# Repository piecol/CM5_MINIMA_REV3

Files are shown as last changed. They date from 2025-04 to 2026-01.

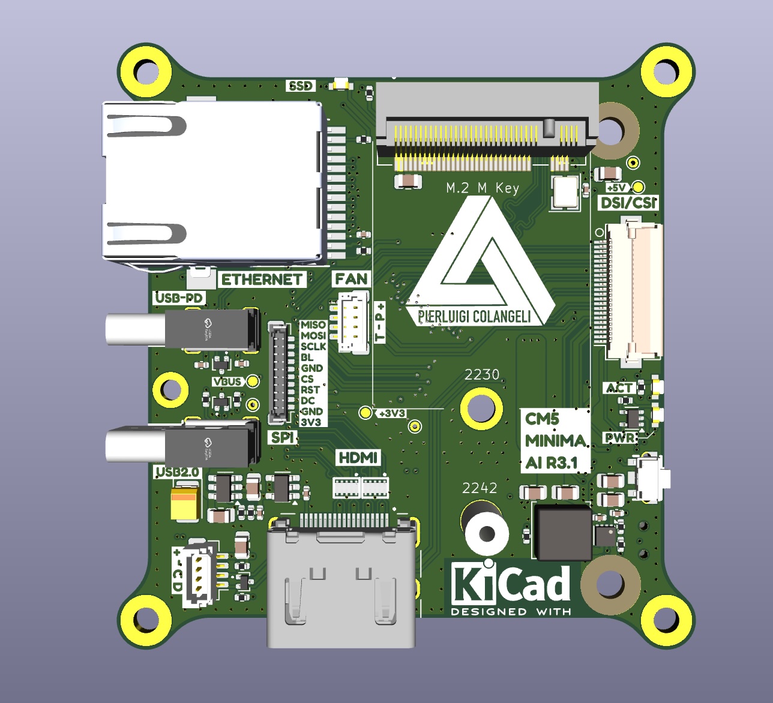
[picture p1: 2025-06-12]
jlcpcb/production_files/front.jpg

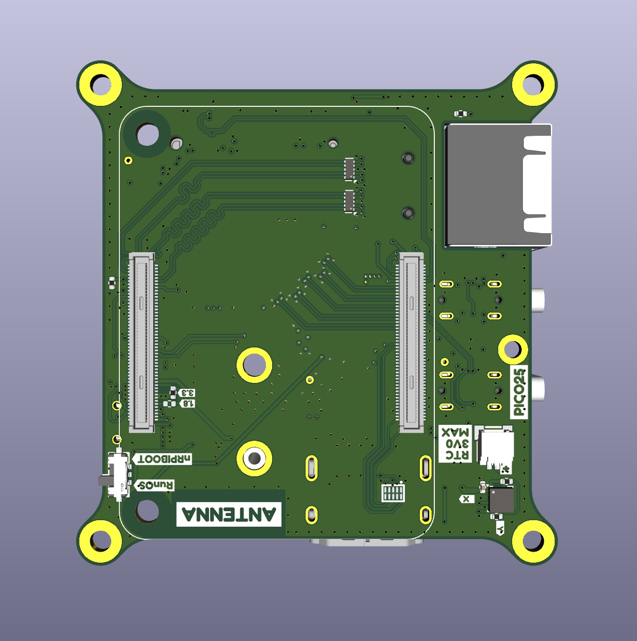
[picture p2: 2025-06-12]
jlcpcb/production_files/back.jpg

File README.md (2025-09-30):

# CM5 MINIMA REV3

## Introduction

The **CM5 MINIMA REV3** is a compact carrier board for the latest Raspberry Pi computing module 5.
It is designed for embedded applications, DIY electronics, and low-power computing projects. Unlike traditional desktop computers, the CM5 is a small, efficient system that integrates essential computing hardware onto a single board. Whether you're a hobbyist, developer, or engineer, this module provides a versatile platform for various applications, including IoT, automation, and custom hardware development.

If you're not familiar with Raspberry Pi or single-board computers (SBCs), think of the CM5 as a miniaturized computer that can handle tasks like data processing, networking, and hardware control, all while fitting in the palm of your hand. 
https://www.raspberrypi.com/products/compute-module-5/?variant=cm5-104032



Get to know the story behind the MINIMA on Hackster.io:

https://www.hackster.io/piecol/tiny-open-source-media-streamer-with-lorawan-what-a98a93

3d

## Designed with KiCad

MINIMA was developed using KiCad, a powerful open-source Electronic Design Automation (EDA) tool. KiCad enables designers to create high-quality PCB layouts and schematics while maintaining full control over their hardware designs. By leveraging open-source tools like KiCad, the CM5 MINIMA REV3 embraces accessibility, collaboration, and innovation in hardware development.

## NextPCB production ready

This project is kindly supported by [NextPCB](https://www.nextpcb.com/), an excellent KiCAD-friendly PCB manufacturer.
Under "nextpcb/production_files" you can find production files to directly place your order.
Explore thier blog https://www.nextpcb.com/blog/exploring-the-cm5-minima-rev3

## Key Features

- **USB-C Power Delivery (PD):** Supports power negotiation for efficient energy use.
- **USB 2.0 Ports:** Connect peripherals such as keyboards, mice, and external storage.
- **Gigabit Ethernet:** High-speed wired networking with a low-profile cutout magjack.
- **HDMI Port:** Output video to external displays for media playback or interface applications.
- **M.2 M Key Slot:** Supports 2230/2242 SSDs for fast storage expansion.
- **CSI/DSI Connector:** Attach camera modules or displays for vision-based applications.
- **LIS3DH STM32 Sensor:** Built-in accelerometer.
- **I2C Connector (3.3V only):** Connect low-power sensors and communication modules.
- **SPI Connector:** Supports high-speed communication with other devices.
- **Fan Connector:** Optional cooling support for high-performance applications.
- **Status LEDs:** Visual indicators for power and system activity.
- **Compact Size:** Measuring only **5.4 × 5.7 cm**, ideal for space-constrained projects.

pcb

## Schematics

[PDF SCHEMATICS](https://github.com/piecol/CM5_MINIMA_REV3/blob/main/CM5_MINIMA_3.pdf)

## Getting Started

To use the **CM5 MINIMA REV3**, you'll need:

- A **USB-C power adapter** that supports Power Delivery (PD).
- A **display (HDMI)** and **input devices (USB keyboard/mouse)** for setup.
- A **network connection** (Ethernet or Wi-Fi via an external adapter if needed).

## Flashing OS

To flash an operating system (OS) to the CM5, use the switch located on the bottom of the board to enable flashing mode. It is equivalent to the "Fit nRPI_BOOT to J2 (disable eMMC Boot) on the IO board jumper." on the CM5 IO board.
Please refere to the official guidelines for further instructions:
https://www.raspberrypi.com/documentation/computers/compute-module.html#set-up-the-io-board

aseembly

## Applications

- **IoT & Smart Devices:** Use sensors and network capabilities to create connected applications.
- **Home Automation:** Control and monitor home devices with minimal power consumption.
- **Embedded Systems:** Develop custom hardware solutions for industrial and consumer electronics.
- **Media Centers:** Play videos and manage digital content on an external display.
- **DIY Projects:** Ideal for makers and educators learning about electronics and programming.

## CNC casing

Custom casing with passive heat-sink was supported by PCBway, grab the .STEP file in the CNC_enclosure folder and order yours.



## Conclusion

The **CM5 MINIMA REV3** is a powerful and flexible computing module that opens up endless possibilities for embedded computing and automation. Whether you're building a smart device, experimenting with sensors, or designing a networked system, this board provides the essential features you need in a compact, energy-efficient form factor.

## **Stackup**:
6L (SIG:PWR | GND | SIG-PWR | PWR | GND | SIG:PWR) 

### If you would like to support me:

"Buy Me A Coffee" (https://www.buymeacoffee.com/pierluigicj)

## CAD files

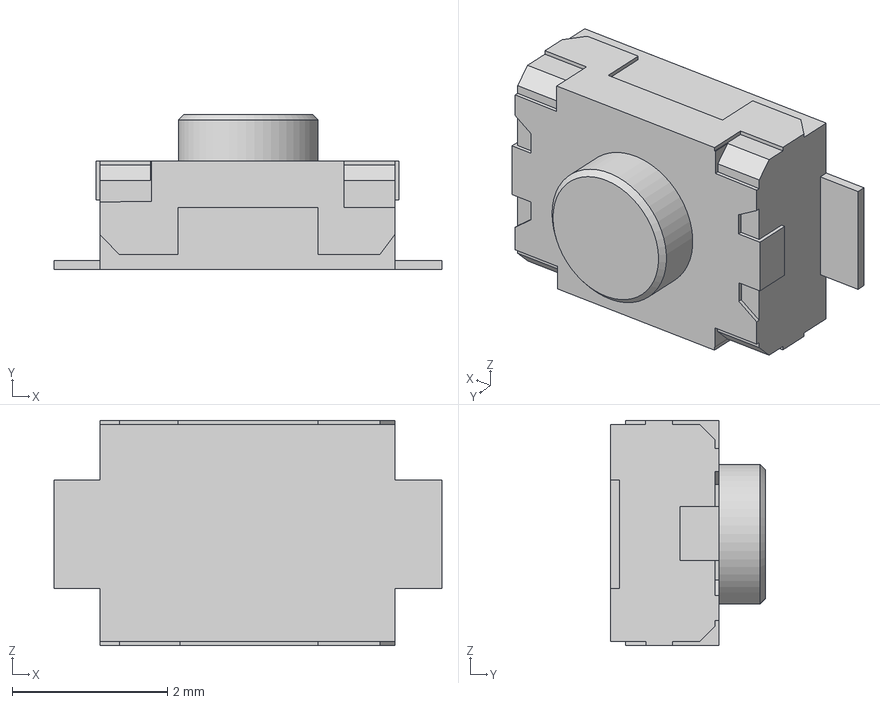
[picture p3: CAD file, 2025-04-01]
3d_lib/3x4x2 tact button.step
5.00 x 2.00 x 2.90 mm

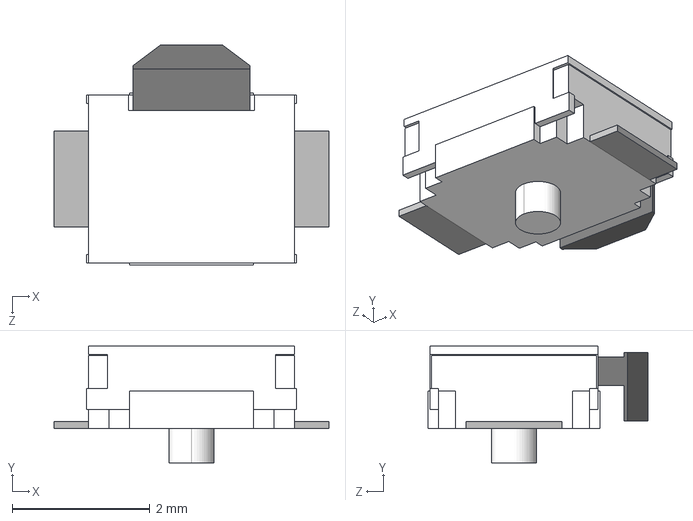
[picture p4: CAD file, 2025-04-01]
3d_lib/LIB_B3U-3000PM-B/B3U-3000PM-B/3D/B3U-3000PM-B.stp
4.00 x 1.70 x 3.20 mm

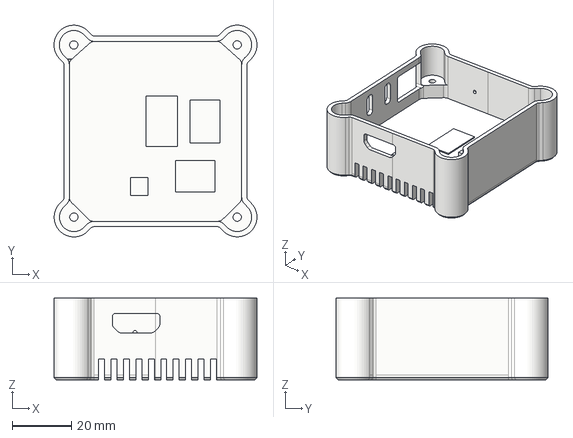
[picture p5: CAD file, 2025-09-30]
CNC_enclosure/MINIMA CASE 3_BOX v1.step
68.3 x 71.3 x 27.4 mm

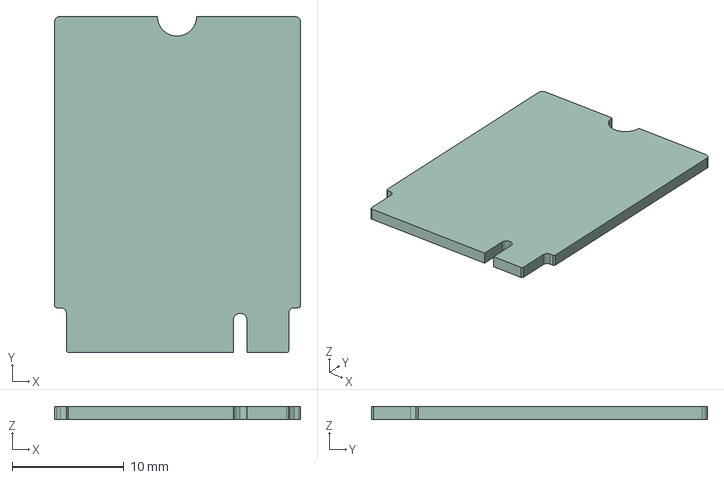
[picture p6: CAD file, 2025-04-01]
3d_lib/M.2-B.step
22.0 x 30.1 x 1.20 mm

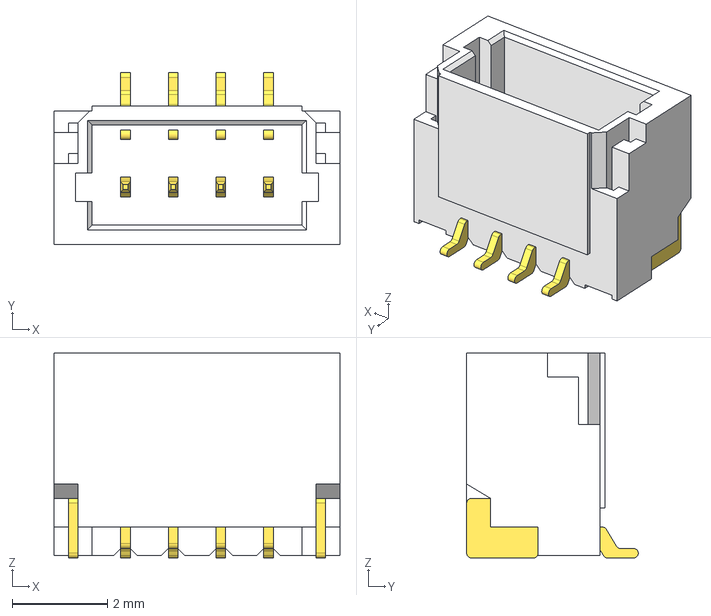
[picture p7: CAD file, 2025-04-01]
3d_lib/BM4B-SRSS-TB.step
6.00 x 3.60 x 4.30 mm

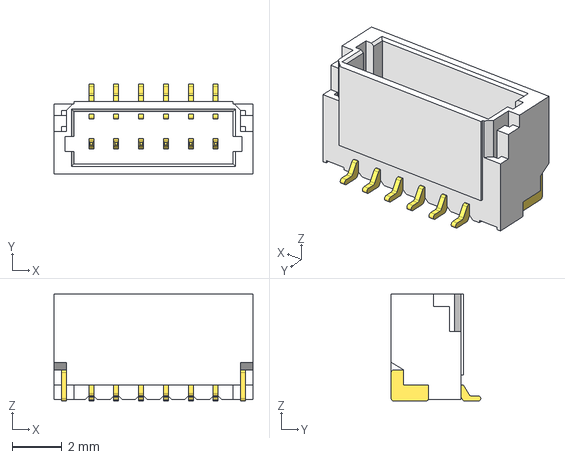
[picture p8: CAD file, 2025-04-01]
3d_lib/BM6B-SRSS-TB.step
8.00 x 3.60 x 4.30 mm

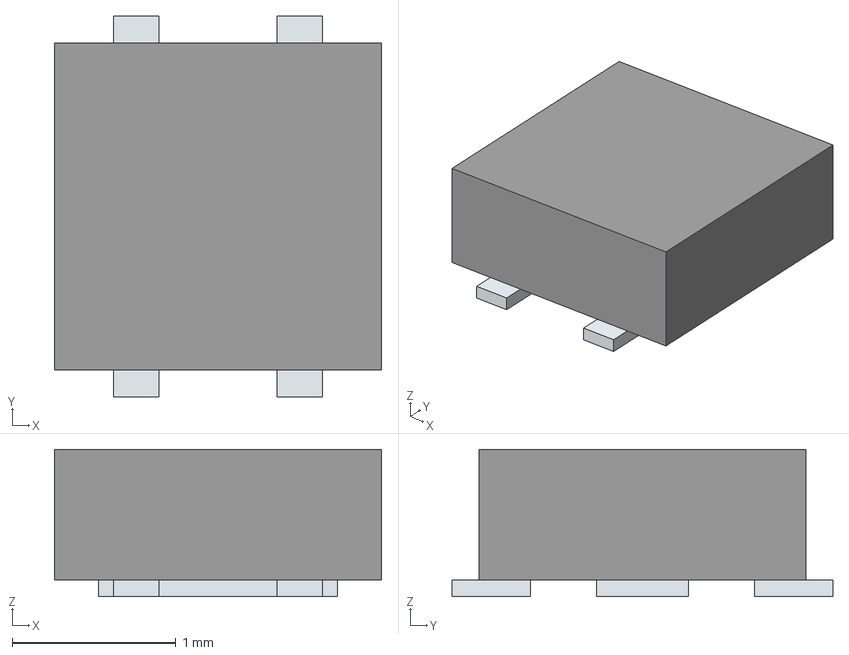
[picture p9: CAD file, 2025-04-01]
3d_lib/SHTC3-TR-10KS.stp
2.00 x 2.33 x 0.9 mm
Pins

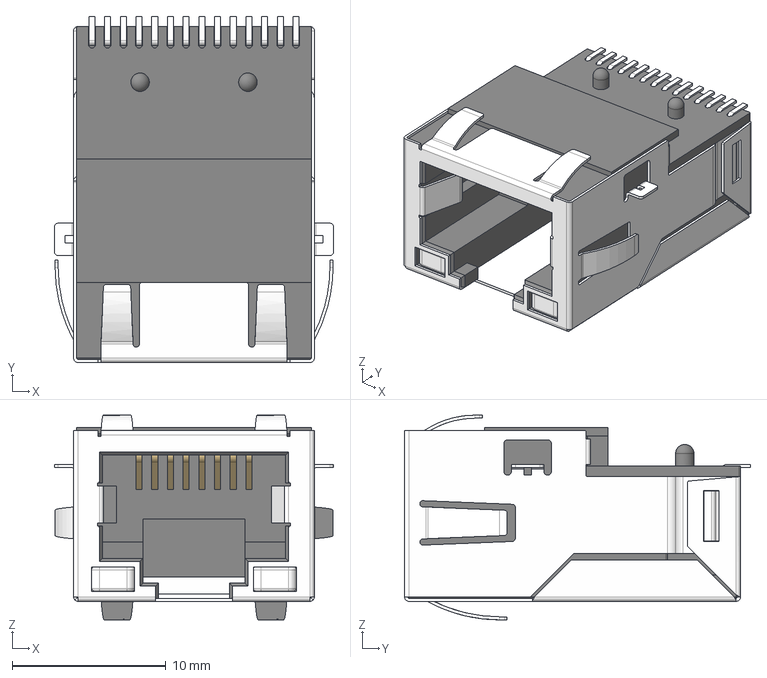
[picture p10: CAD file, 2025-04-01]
3d_lib/WE-RJ45LAN-7498111120AR (rev1).stp
18.1 x 22.5 x 13.3 mm
Shielding
Insulator x 3

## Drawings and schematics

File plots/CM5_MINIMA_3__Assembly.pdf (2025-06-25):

# kibuzzard-67CC6BD3

# kibuzzard-6772DA33

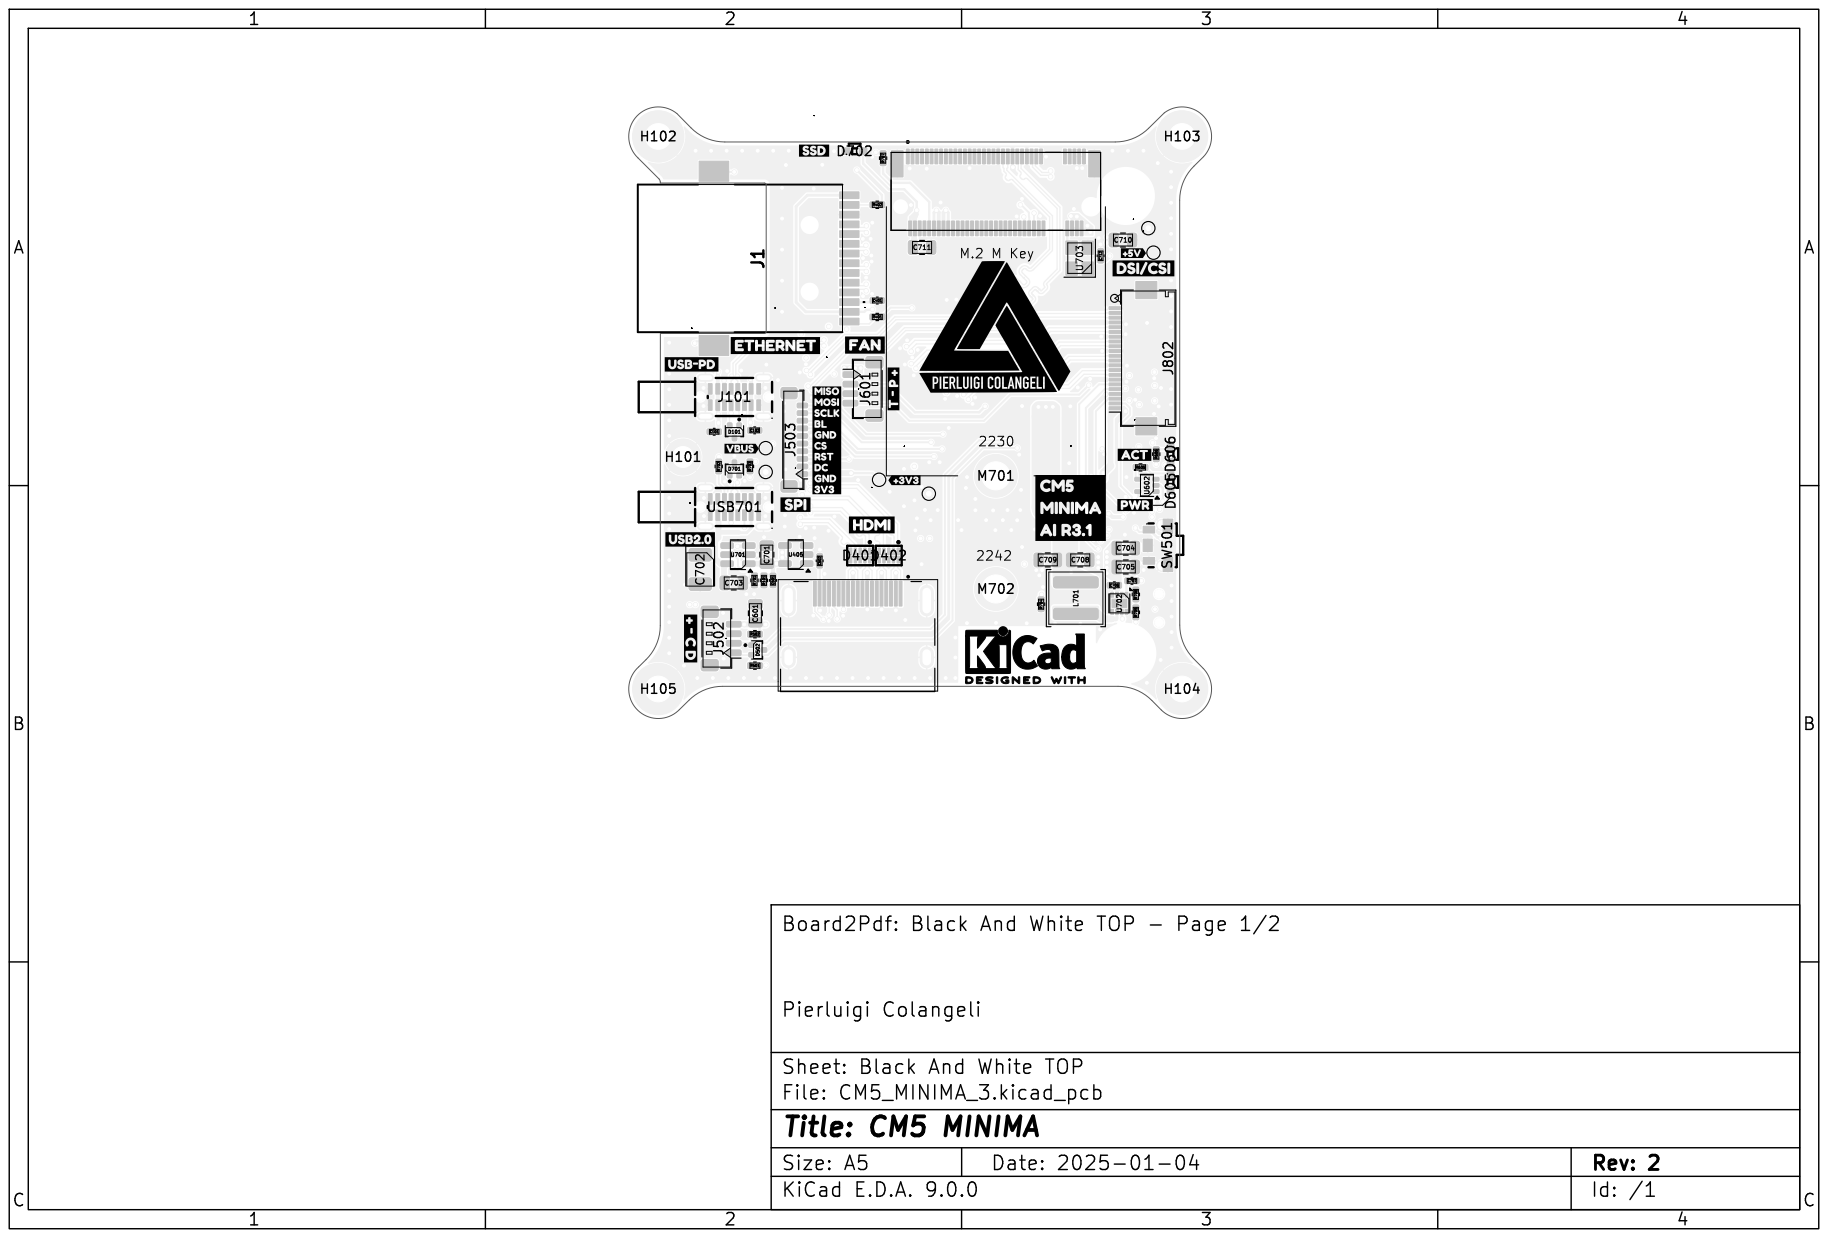
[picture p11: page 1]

File: CM5_MINIMA_3.kicad_pcb Sheet: Black And White TOP
Id: /1 Title: CM5 MINIMA

kibuzzard-67EBF0A0 1 | 2 | 3 | 4

A

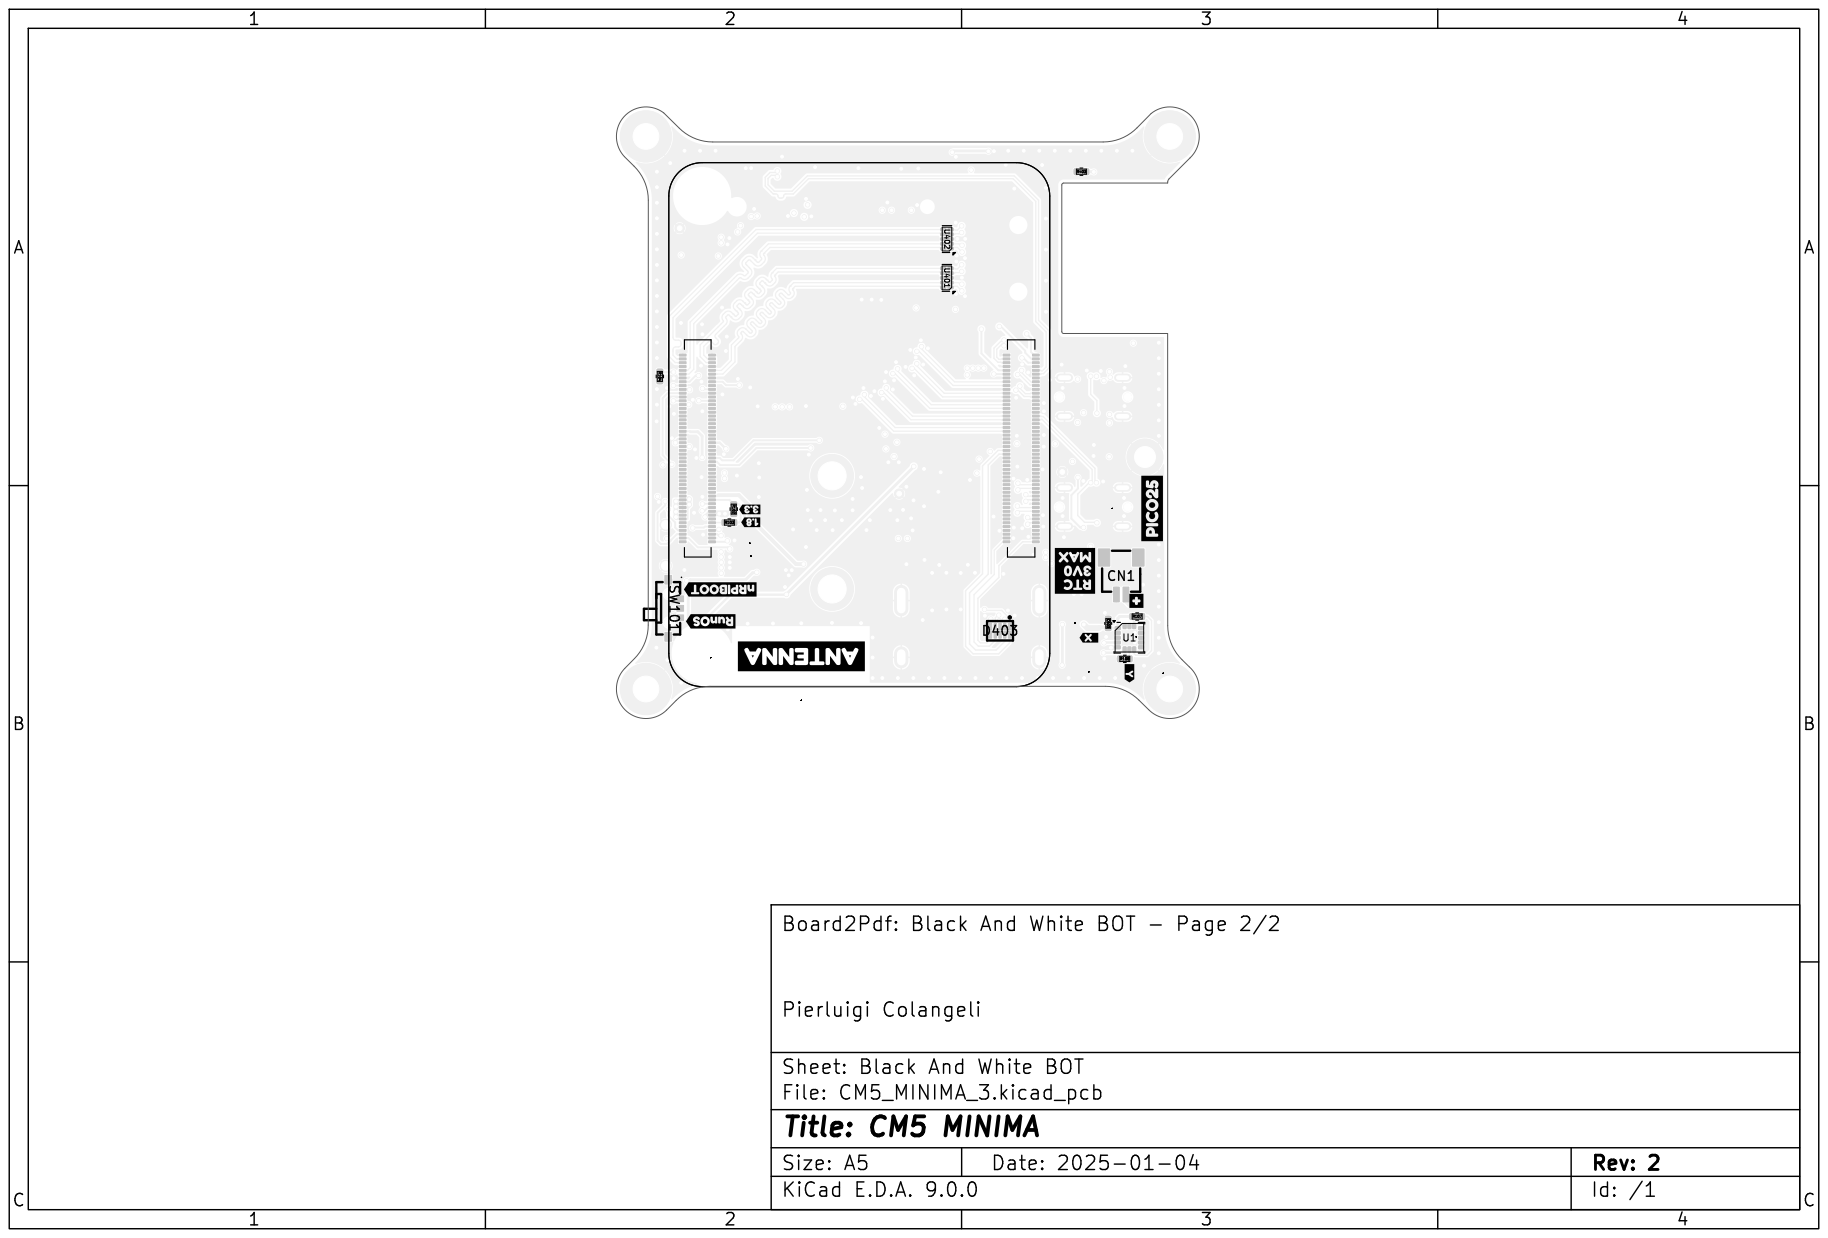
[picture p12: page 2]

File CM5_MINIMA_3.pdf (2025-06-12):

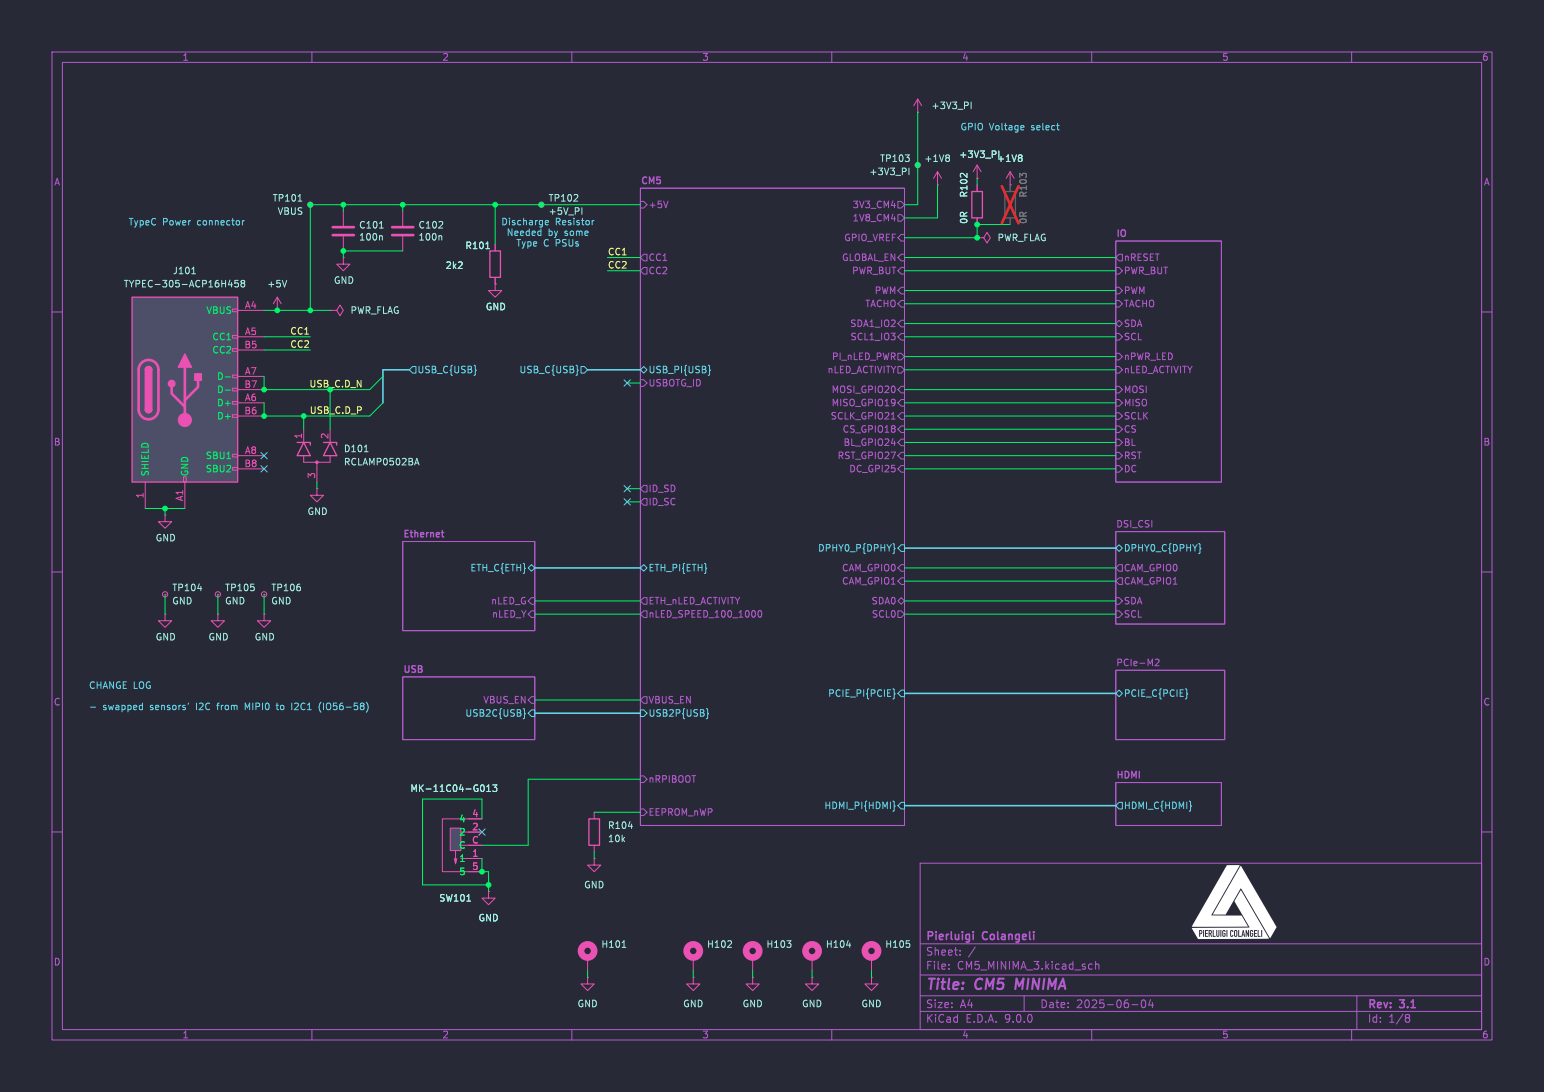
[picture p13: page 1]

HDMI_C{HDMI} HDMI SCL SDA DPHY0_C{DPHY} CAM_GPIO0 CAM_GPIO1 DSI_CSI nRESET SDA
SCL PWR_BUT PWM
TACHO MOSI MISO

File: CM5_MINIMA_3.kicad_sch Sheet: / Pierluigi Colangeli VBUS_EN

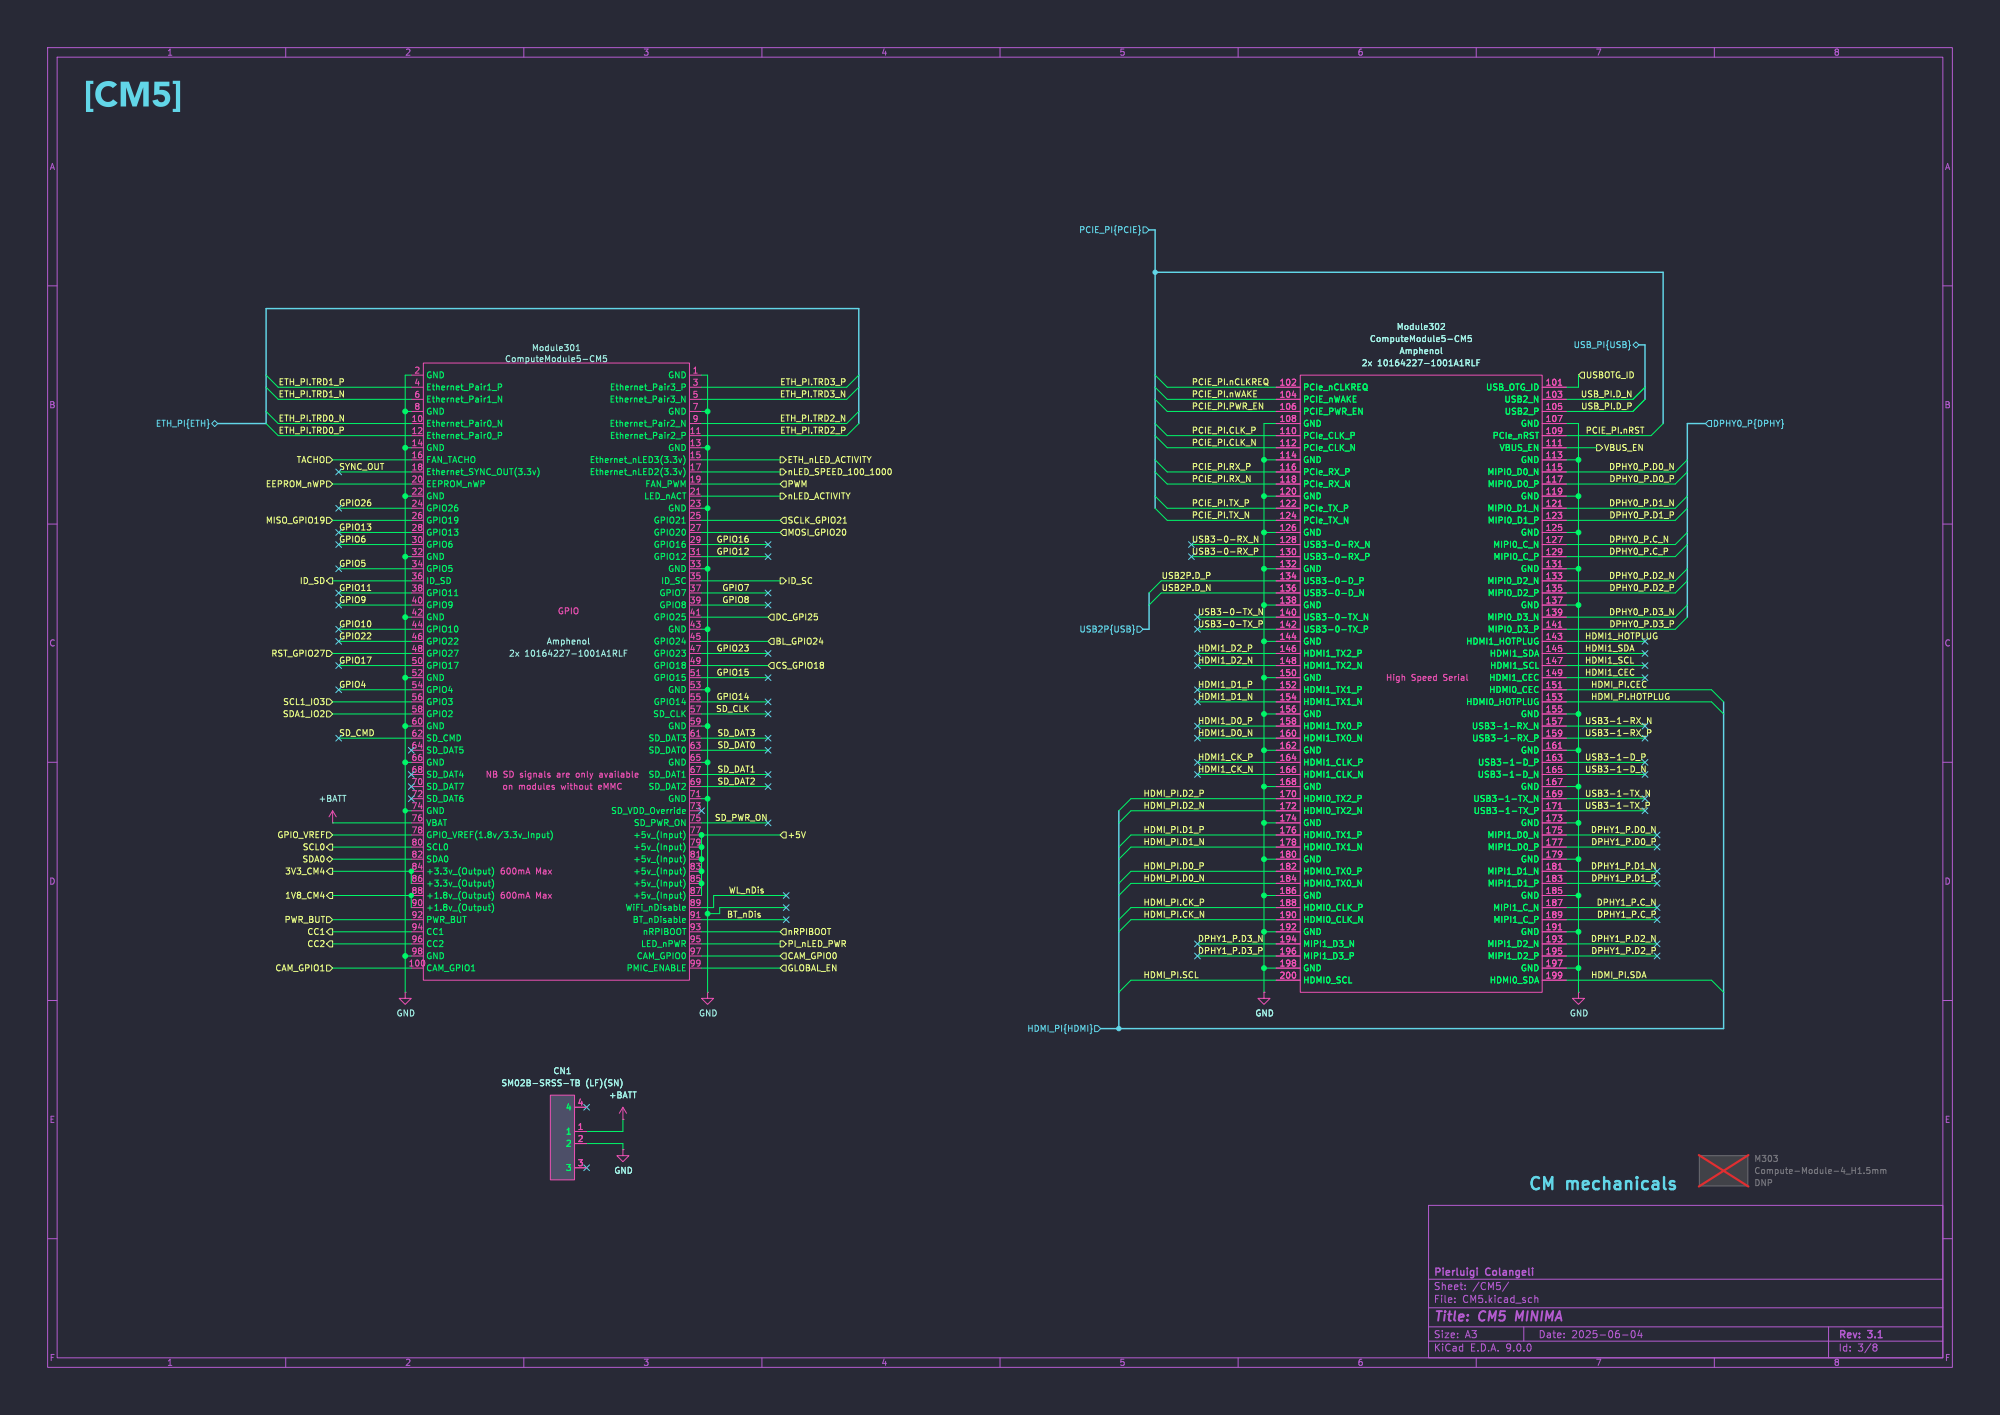
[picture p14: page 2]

USB_PI{USB} MISO_GPIO19 RST_GPIO27
ID_SD 36 GPIO11 38 GPIO9 40 GND 42 GPIO10 44 GPIO22 46 GPIO27 48 GPIO17 50 GND 52 GPIO4 54 GPIO3 56 GPIO2 58 GND 60 SD_CMD 62 SD_DAT5 64 GND 66 SD_DAT4 68 SD_DAT7 70 SD_DAT6 72 GND 74 VBAT 76 GPIO_VREF(1.8v/3.3v_Input) 78 SCL0 80 SDA0 82 +3.3v_(Output) 84 +3.3v_(Output) 86 +1.8v_(Output) 88 +1.8v_(Output) 90 PWR_BUT 92 CC1 94 CC2 96 GND 98 CAM_GPIO1 100

GND 2 Ethernet_Pair1_P 4 Ethernet_Pair1_N 6 GND 8 Ethernet_Pair0_N 10 Ethernet_Pair0_P 12 GND 14 FAN_TACHO 16 Ethernet_SYNC_OUT(3.3v) 18 EEPROM_nWP 20 GND 22 GPIO26 24 GPIO19 26 GPIO13 28 GPIO6 30 GND 32 GPIO5 34

on modules without eMMC GPIO

600mA Max 600mA Max NB SD signals are only available

File: CM5.kicad_sch Sheet: /CM5/ Pierluigi Colangeli GND

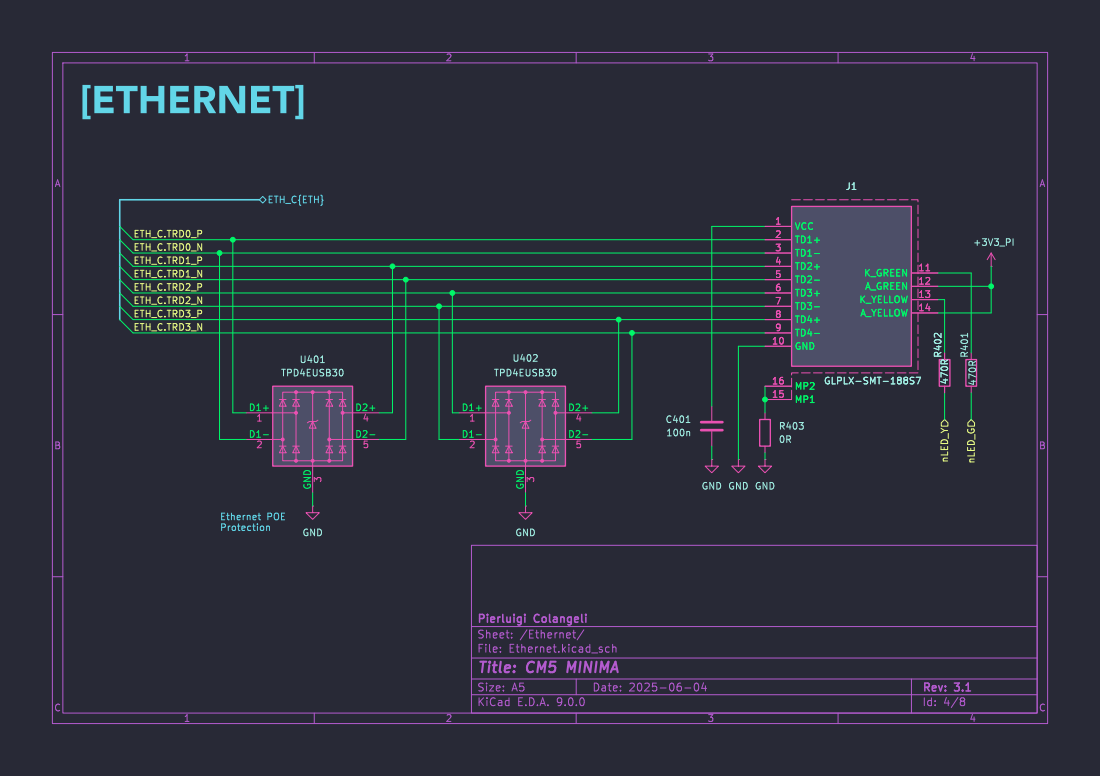
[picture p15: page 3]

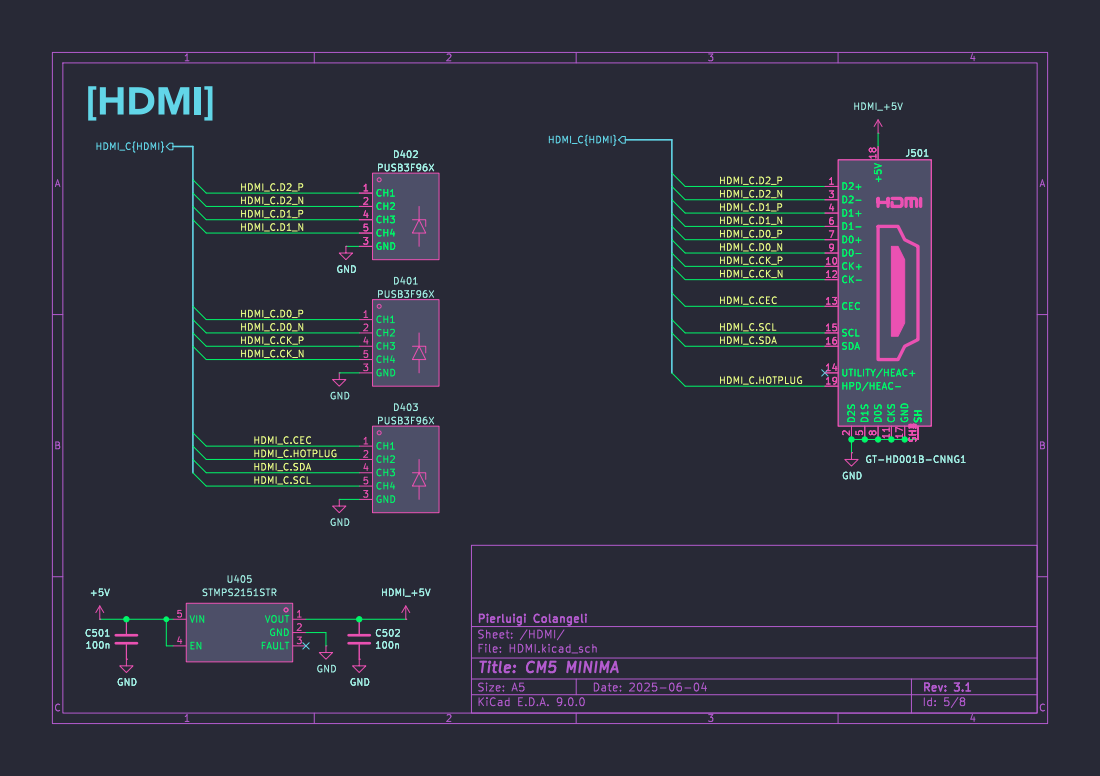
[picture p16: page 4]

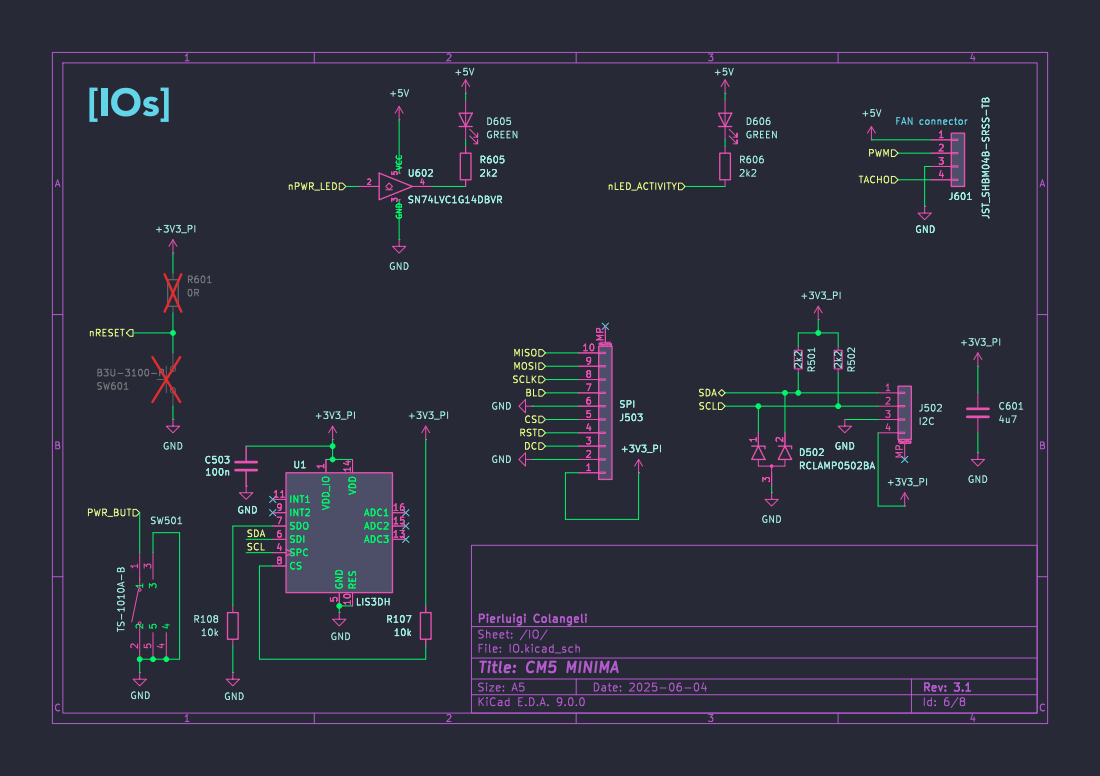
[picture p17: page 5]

nLED_ACTIVITY RST DC MOSI MISO

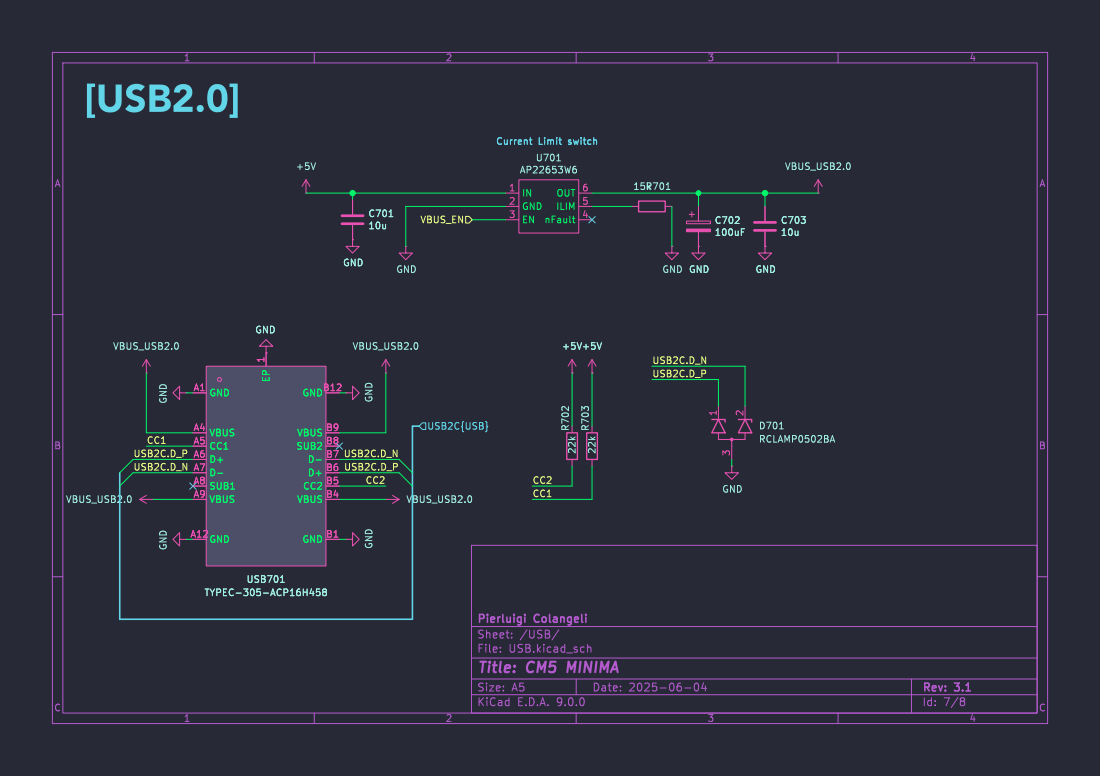
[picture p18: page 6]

1 GNDB12 VBUS B9 SUB2 B8 D- B7 D+ B6 CC2 B5 VBUS B4 GND B1 USB701 TYPEC-305-ACP16H458 GND GND GND GND

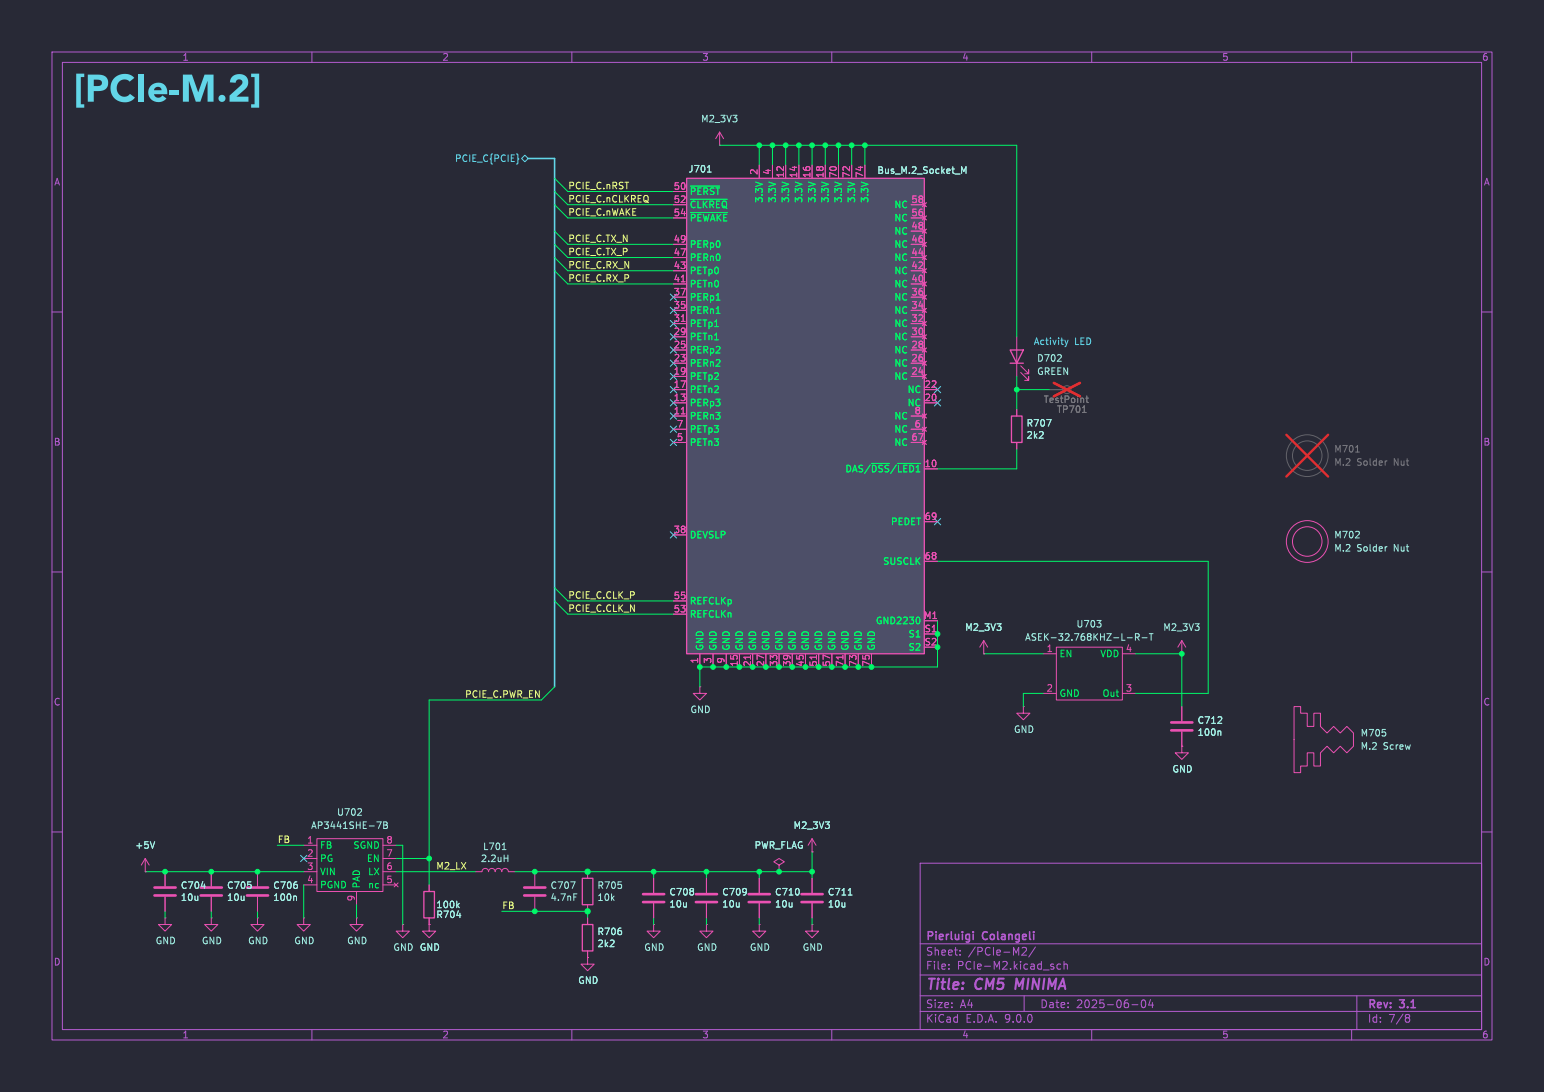
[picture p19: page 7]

4 GND 33 3.3V 12 GND 39 3.3V 14 GND 45 3.3V 16 GND 51 3.3V 18 GND 57 3.3V 70 GND 71 3.3V 72 GND 73 3.3V 74 GND 75 NC 58 NC 56 NC 48 NC 46 NC 44 NC 42 NC 40 NC 36 NC 34 NC 32 NC 30 NC 28 NC 26 NC 24 NC 8 NC 6 NC 67 NC 22 NC 20 DAS/~{DSS}/~{LED1} 10 PEDET 69 SUSCLK 68 GND2230 M1 S1 S1 S2 S2 C705

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

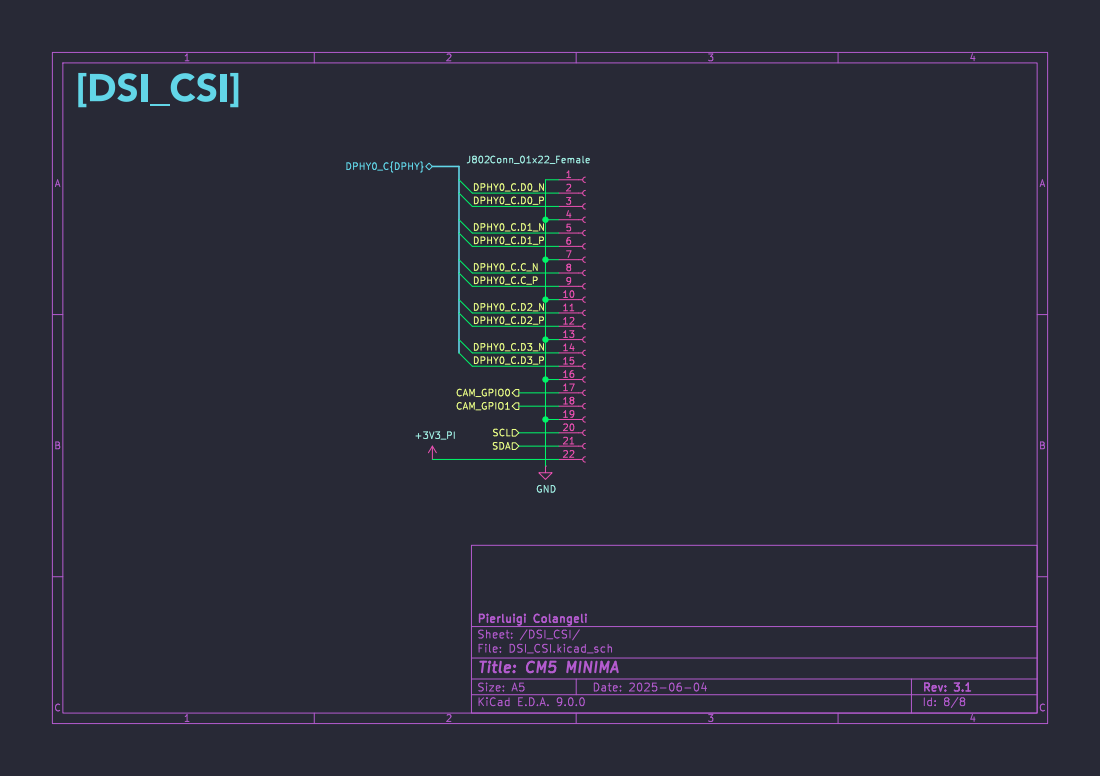
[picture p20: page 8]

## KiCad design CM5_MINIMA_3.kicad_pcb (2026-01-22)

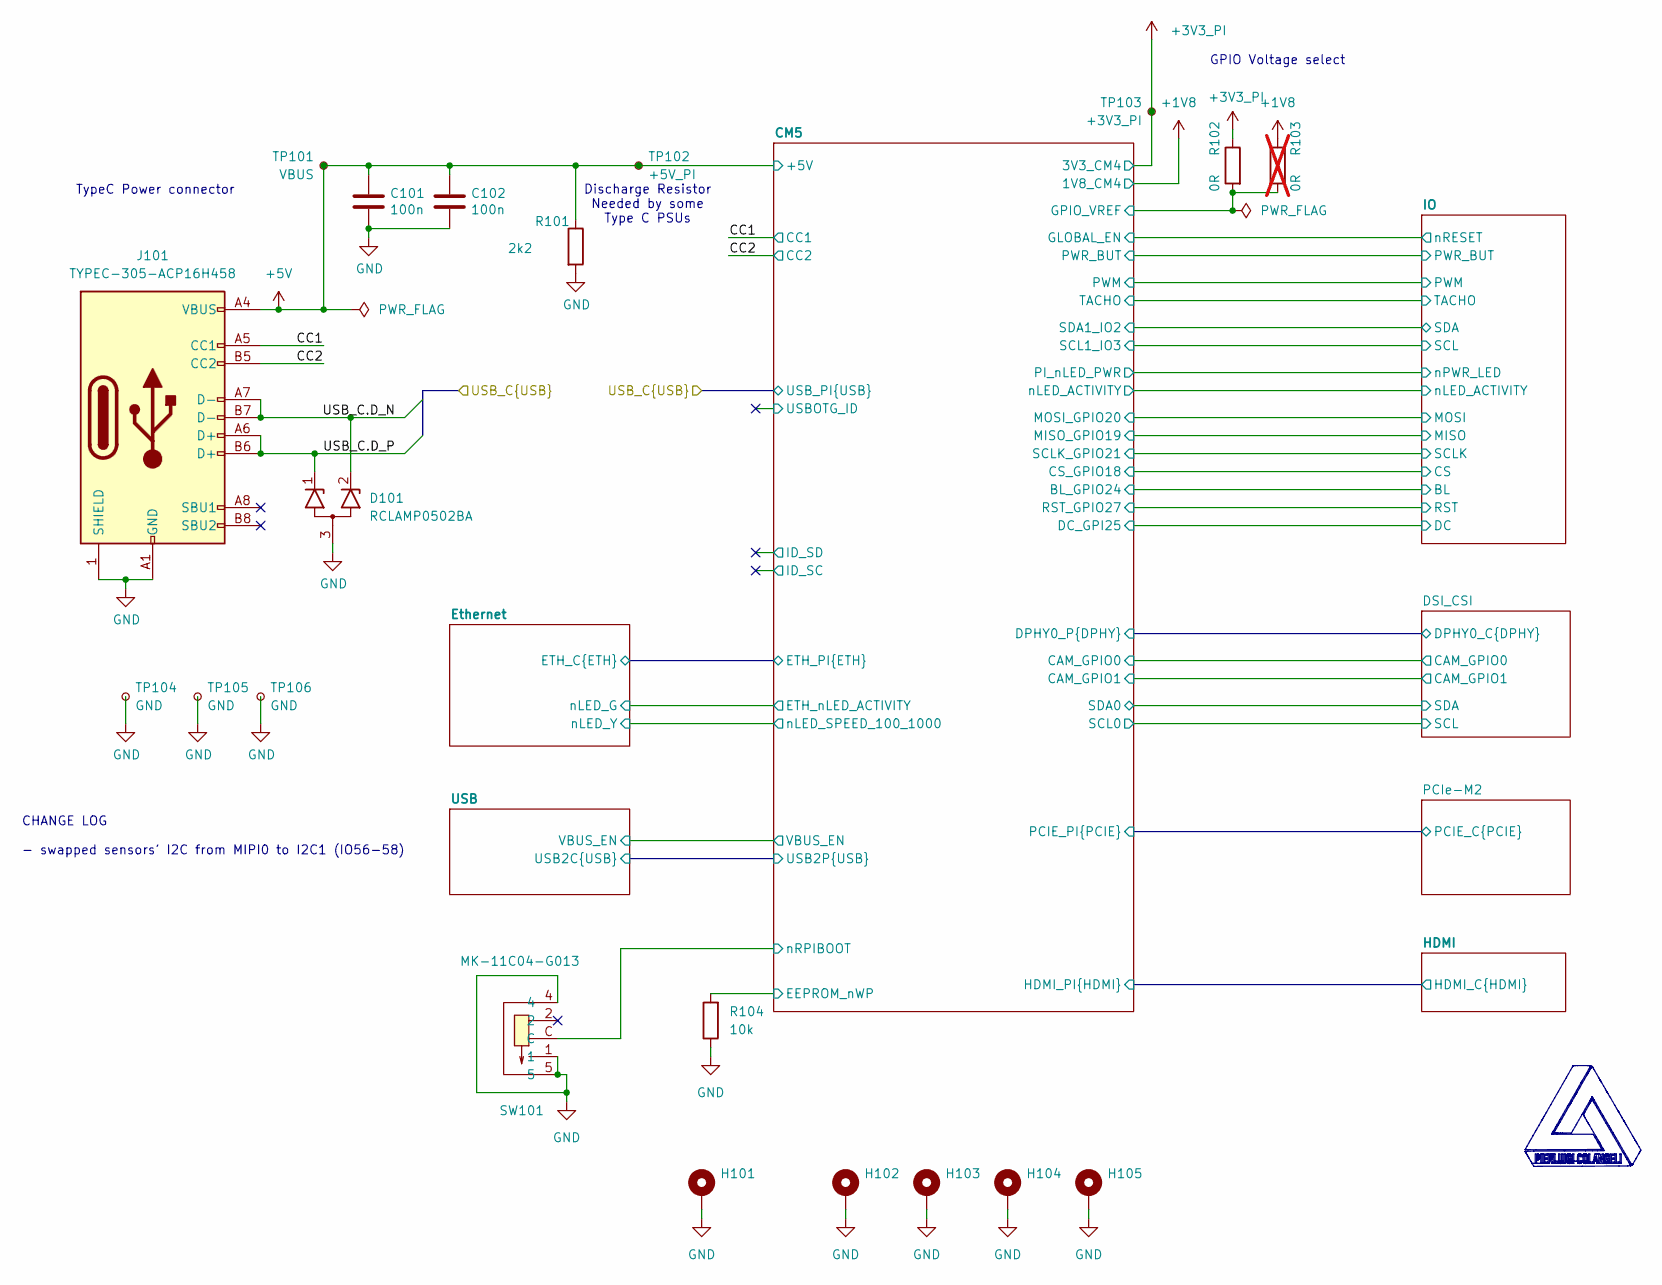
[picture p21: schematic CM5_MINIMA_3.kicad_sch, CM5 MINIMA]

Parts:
C101, C102: 100n; C_0402_1005Metric; Part Description 0.1uF 10% 16V Ceramic Capacitor X7R 040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
D101: RCLAMP0502BA; SOT-416
H101: MountingHole_Pad; MountingHole_2.2mm_M2_DIN965_Pad_TopBottom
H102, H103, H104, H105: MountingHole_Pad; MountingHole_2.7mm_Pad
J101: TYPEC-305-ACP16H458; USB-C-SMD_TYPEC-305-ACP16H458; Part Description USBC USB2 data and power connector
R101: 2k2; R_0402_1005Metric
R102: 0R; R_0402_1005Metric; Part Description Resistor 0R M2012 5%
R103: 0R; R_0402_1005Metric; not fitted
R104: 10k; R_0402_1005Metric
SW101: MK-11C04-G013; SW-SMD_MK-11C04-G013; LCSC Part C778185
TP101: VBUS; TestPoint_Pad_D1.0mm
TP102: +5V_PI; TestPoint_Pad_D1.0mm
TP103: +3V3_PI; TestPoint_Pad_D1.0mm
TP104, TP105, TP106: GND; TestPoint_THTPad_D1.0mm_Drill0.5mm

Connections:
+1V8: R103.1; also elsewhere on the board
+3V3_PI: R102.1, TP103.1; also elsewhere on the board
+5V: C101.1, C102.1, J101.A4 (VBUS), J101.A9 (VBUS), J101.B4 (VBUS), J101.B9 (VBUS), R101.1, TP101.1, TP102.1; also elsewhere on the board
/CC1: J101.A5 (CC1); also elsewhere on the board
/CC2: J101.B5 (CC2); also elsewhere on the board
/CM5/EEPROM_nWP: R104.2; also elsewhere on the board
/CM5/GPIO_VREF: R102.2, R103.2; also elsewhere on the board
/CM5/nRPIBOOT: SW101.C; also elsewhere on the board
/USB_C.D_N: D101.2 (K2), J101.A7 (D-), J101.B7 (D-); also elsewhere on the board
/USB_C.D_P: D101.1 (K1), J101.A6 (D+), J101.B6 (D+); also elsewhere on the board
GND: C101.2, C102.2, D101.3 (A), H101.1, H102.1, H103.1, H104.1, H105.1, J101.1 (SHIELD), J101.A1 (GND), J101.A12 (GND), J101.B1 (GND), J101.B12 (GND), R101.2, R104.1, SW101.1, SW101.4, SW101.5, TP104.1, TP105.1, TP106.1; also elsewhere on the board

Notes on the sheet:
CHANGE LOG - swapped sensors' I2C from MIPI0 to I2C1 (IO56-58)
GPIO Voltage select
TypeC Power connector
Discharge Resistor Needed by some Type C PSUs

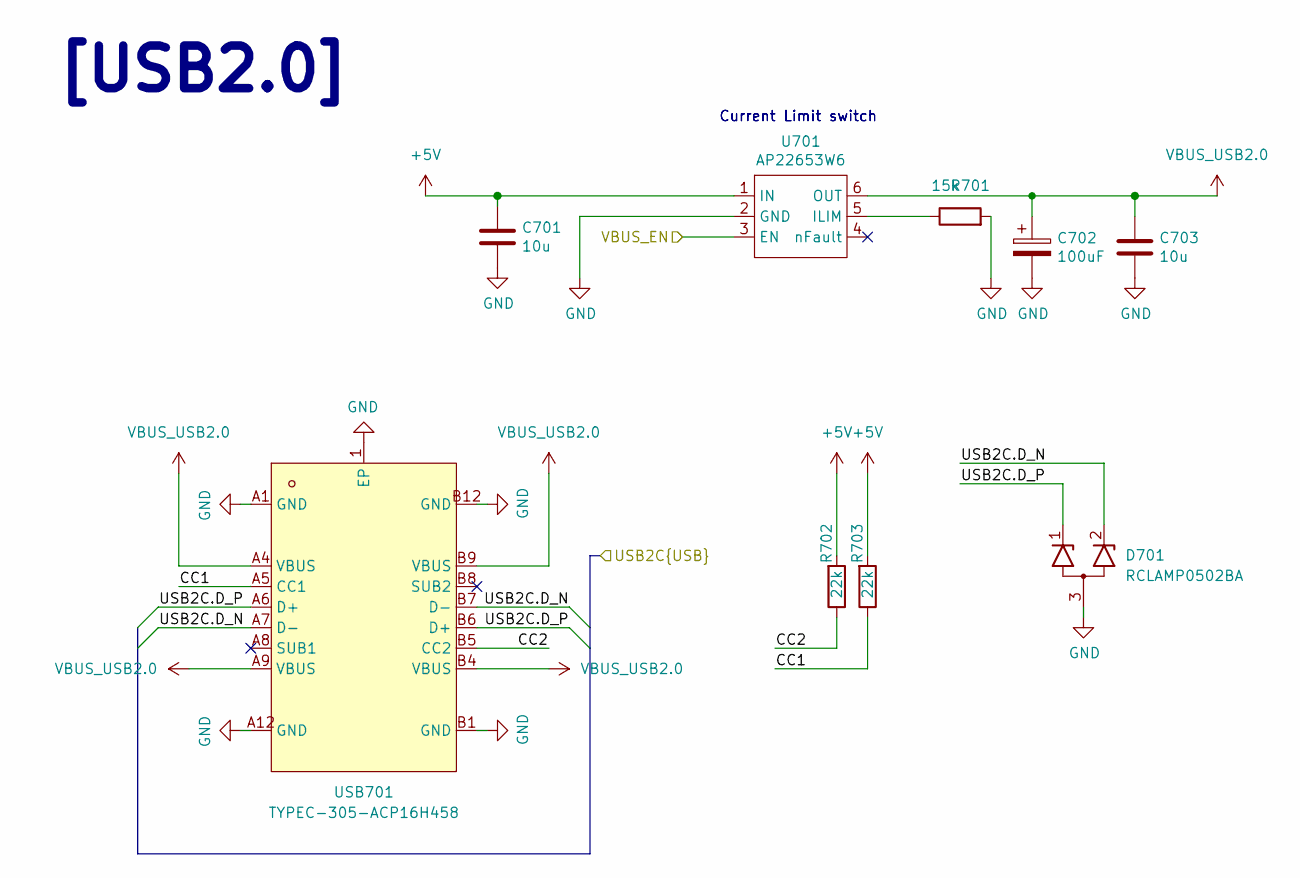
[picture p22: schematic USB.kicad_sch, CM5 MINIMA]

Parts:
C701, C703: 10u; C_0805_2012Metric; Part Description 10uF 10% 10V Ceramic Capacitor X7R 0805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
C702: 100uF; CP_EIA-3528-21_Kemet-B; Part Description 100uF 6.3V 1.7Ω@100kHz ±10% CASE-B-3528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
D701: RCLAMP0502BA; SOT-416
R701: 15k; R_0402_1005Metric; Part Description Resistor 15K M1005 1% 63mW
R702, R703: 22k; R_0402_1005Metric
U701: AP22653W6; SOT-23-6; Part Description Power Switch/Driver 1:1 P-Channel 2.1A 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
USB701: TYPEC-305-ACP16H458; USB-C-SMD_TYPEC-305-ACP16H458; LCSC Part C5454943

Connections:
+5V: C701.1, R702.2, R703.2, U701.1 (IN); also elsewhere on the board
/CM5/USB2P.D_N: D701.2 (K2), USB701.A7 (D-), USB701.B7 (D-); also elsewhere on the board
/CM5/USB2P.D_P: D701.1 (K1), USB701.A6 (D+), USB701.B6 (D+); also elsewhere on the board
/CM5/VBUS_EN: U701.3 (EN); also elsewhere on the board
/USB/CC1: R703.1, USB701.A5 (CC1)
/USB/CC2: R702.1, USB701.B5 (CC2)
GND: C701.2, C702.2, C703.2, D701.3 (A), R701.2, U701.2 (GND), USB701.1 (EP), USB701.A1 (GND), USB701.A12 (GND), USB701.B1 (GND), USB701.B12 (GND); also elsewhere on the board
unnamed: R701.1, U701.5 (ILIM)
VBUS_USB2.0: C702.1, C703.1, U701.6 (OUT), USB701.A4 (VBUS), USB701.A9 (VBUS), USB701.B4 (VBUS), USB701.B9 (VBUS)

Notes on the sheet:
[USB2.0]
Current Limit switch

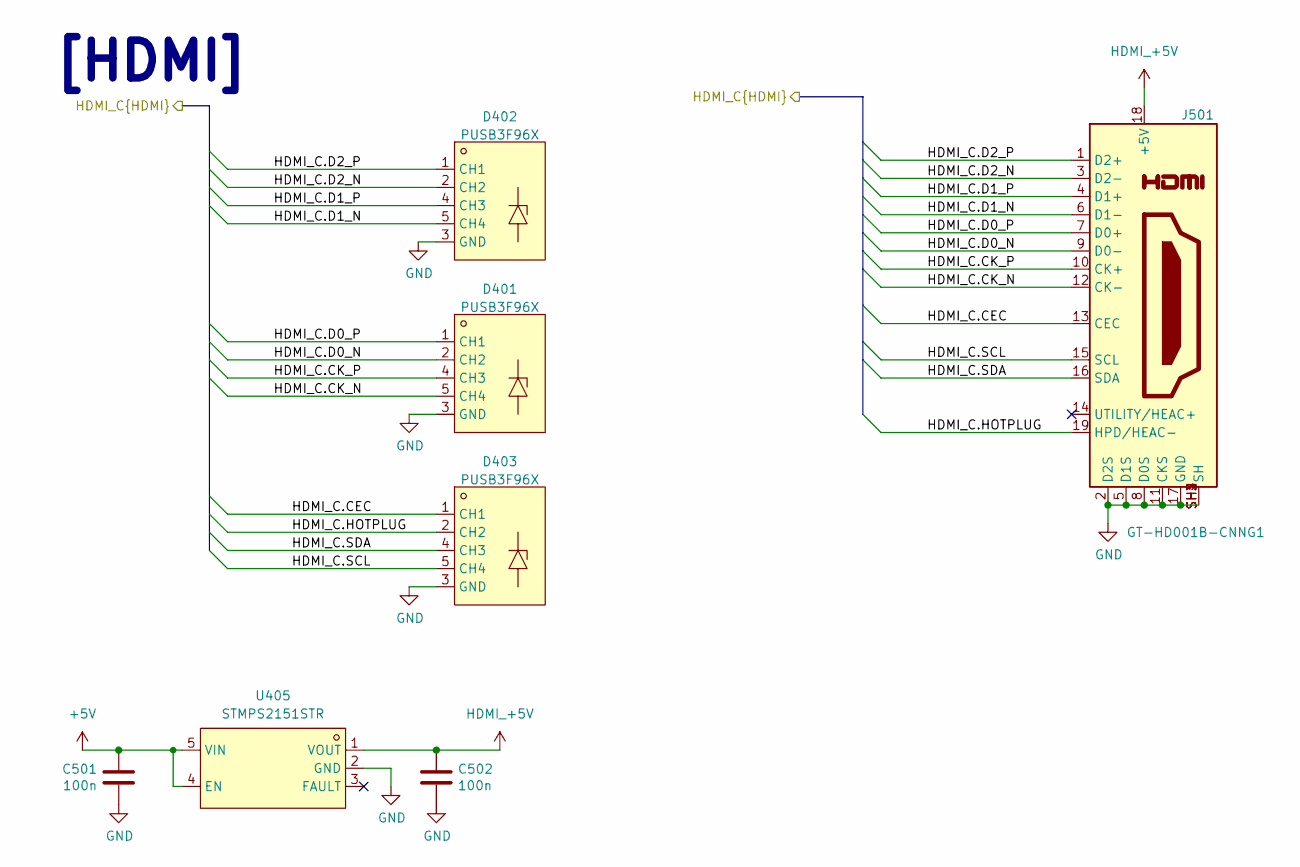
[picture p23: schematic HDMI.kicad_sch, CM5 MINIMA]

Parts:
C501, C502: 100n; C_0402_1005Metric; Part Description 0.1uF 10% 16V Ceramic Capacitor X7R 040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
D401, D402, D403: PUSB3F96X; DFN2510A-10_L2.5-W1.0-P0.50-BL; LCSC Part C478121
J501: GT-HD001B-CNNG1; EDAC 690-019-298-412; Part Description HDMI Connector, Right Angle, 19 Contact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
U405: STMPS2151STR; SOT-23-5; LCSC Part C135998

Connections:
+5V: C501.1, U405.4 (EN), U405.5 (VIN); also elsewhere on the board
/CM5/HDMI_PI.CEC: D403.1 (CH1), D403.10 (NC), J501.13 (CEC); also elsewhere on the board
/CM5/HDMI_PI.CK_N: D401.5 (CH4), D401.6 (NC), J501.12 (CK-); also elsewhere on the board
/CM5/HDMI_PI.CK_P: D401.4 (CH3), D401.7 (NC), J501.10 (CK+); also elsewhere on the board
/CM5/HDMI_PI.D0_N: D401.2 (CH2), D401.9 (NC), J501.9 (D0-); also elsewhere on the board
/CM5/HDMI_PI.D0_P: D401.1 (CH1), D401.10 (NC), J501.7 (D0+); also elsewhere on the board
/CM5/HDMI_PI.D1_N: D402.5 (CH4), D402.6 (NC), J501.6 (D1-); also elsewhere on the board
/CM5/HDMI_PI.D1_P: D402.4 (CH3), D402.7 (NC), J501.4 (D1+); also elsewhere on the board
/CM5/HDMI_PI.D2_N: D402.2 (CH2), D402.9 (NC), J501.3 (D2-); also elsewhere on the board
/CM5/HDMI_PI.D2_P: D402.1 (CH1), D402.10 (NC), J501.1 (D2+); also elsewhere on the board
/CM5/HDMI_PI.HOTPLUG: D403.2 (CH2), D403.9 (NC), J501.19 (HPD/HEAC-); also elsewhere on the board
/CM5/HDMI_PI.SCL: D403.5 (CH4), D403.6 (NC), J501.15 (SCL); also elsewhere on the board
/CM5/HDMI_PI.SDA: D403.4 (CH3), D403.7 (NC), J501.16 (SDA); also elsewhere on the board
GND: C501.2, C502.2, D401.3 (GND), D401.8 (GND), D402.3 (GND), D402.8 (GND), D403.3 (GND), D403.8 (GND), J501.2 (D2S), J501.5 (D1S), J501.8 (D0S), J501.11 (CKS), J501.17 (GND), J501.SH1 (SH), J501.SH2 (SH), J501.SH3 (SH), J501.SH4 (SH), U405.2 (GND); also elsewhere on the board
HDMI_+5V: C502.1, J501.18 (+5V), U405.1 (VOUT)

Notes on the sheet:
[HDMI]

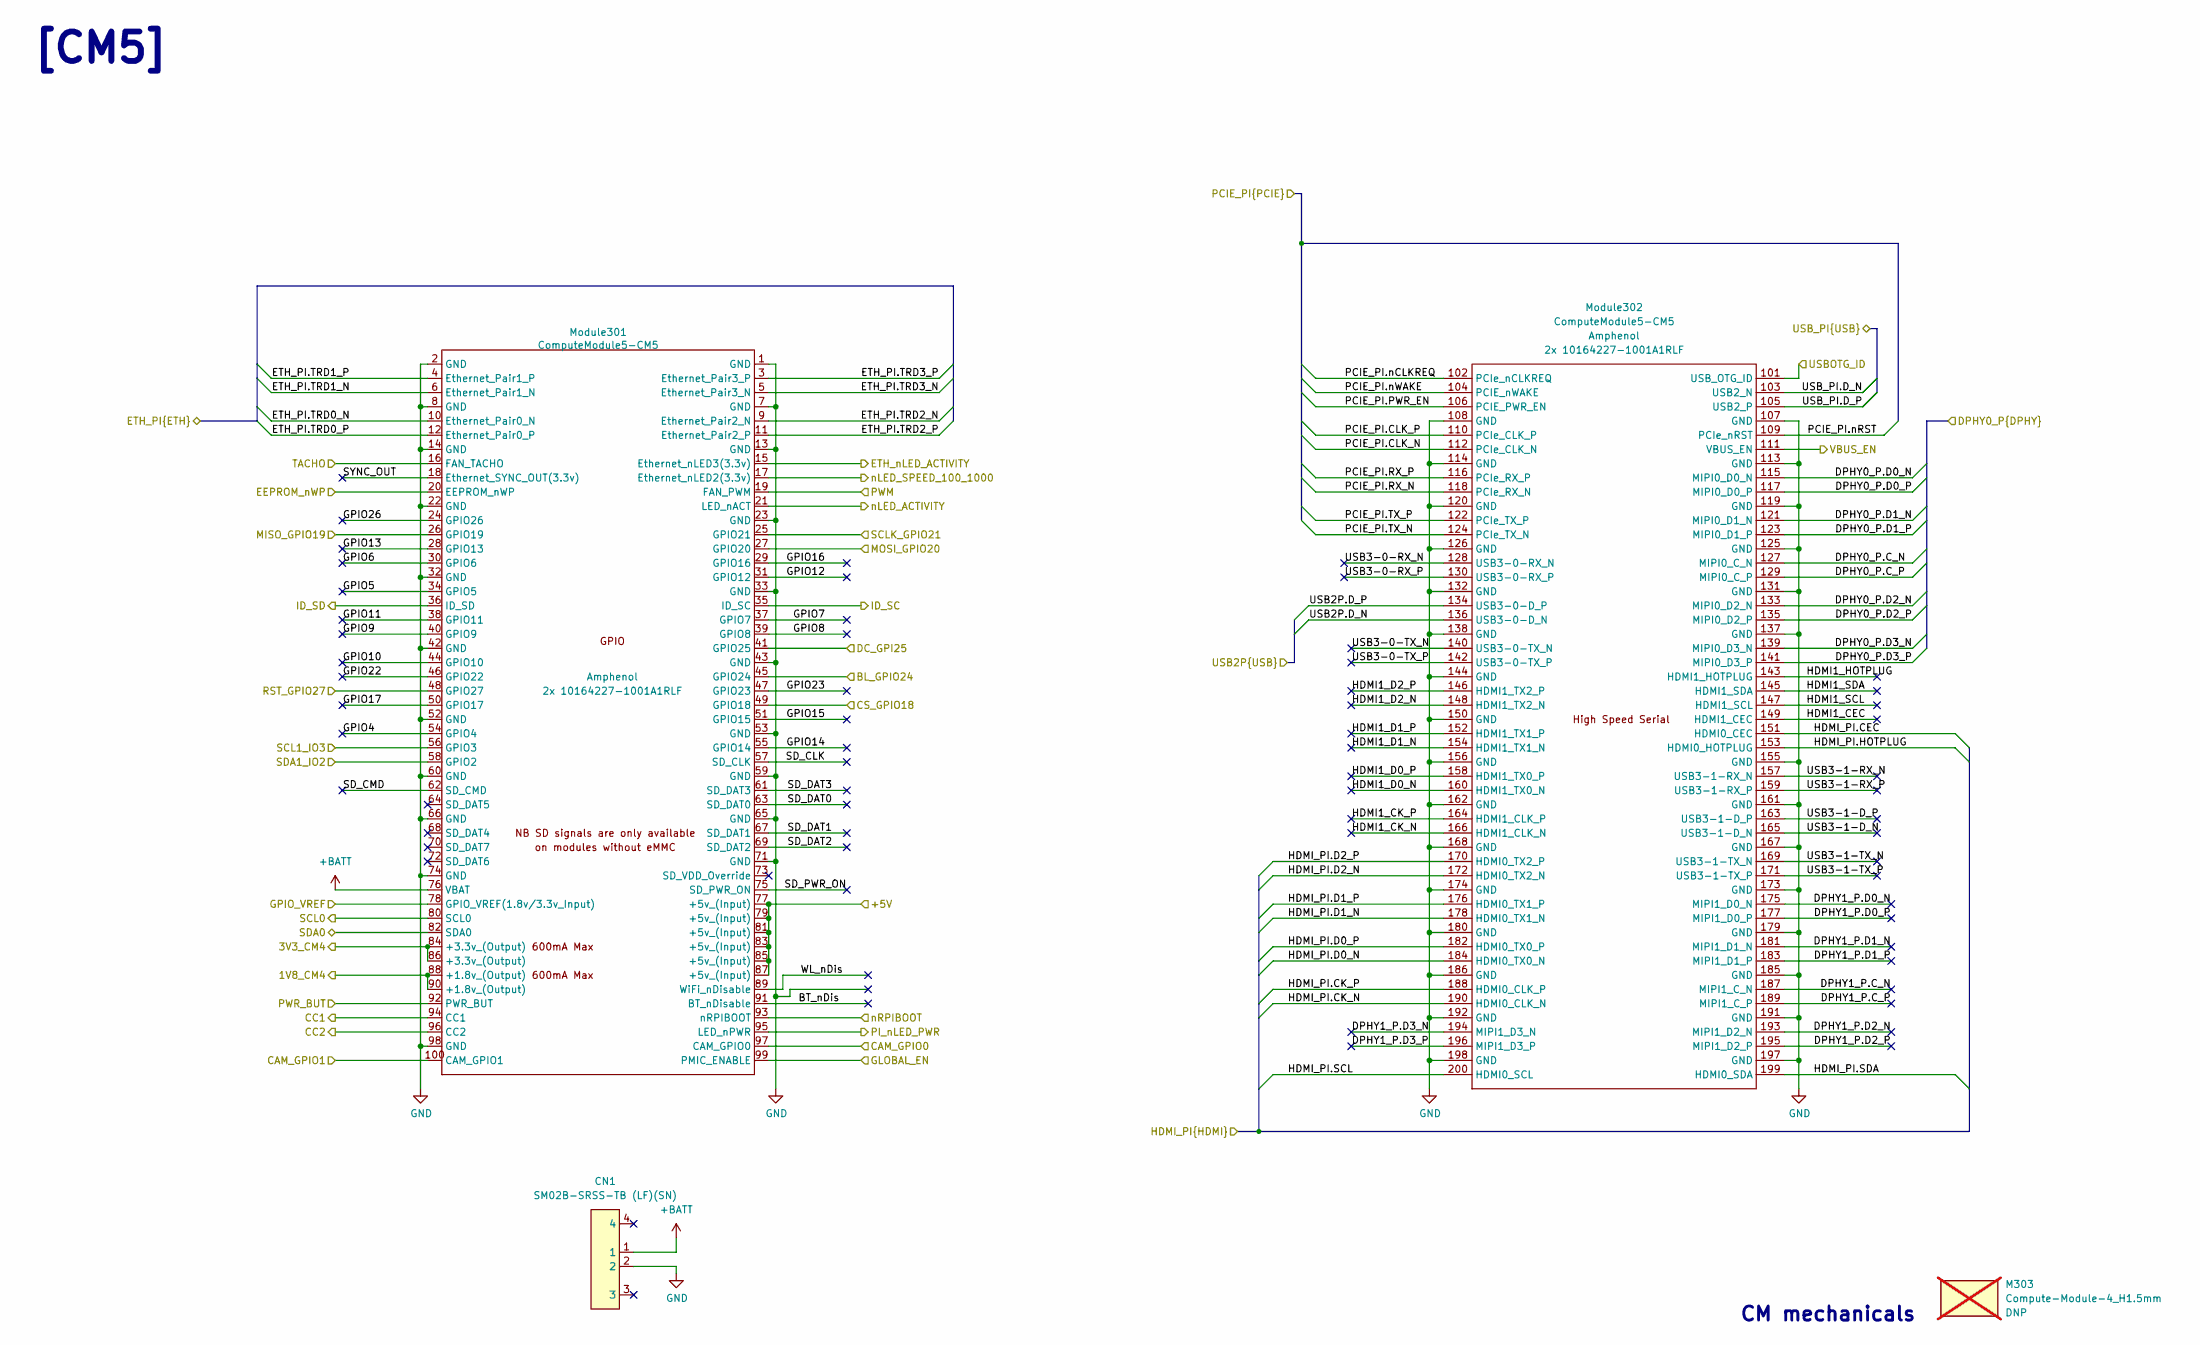
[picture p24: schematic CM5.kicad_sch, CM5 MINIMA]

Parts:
CN1: SM02B-SRSS-TB (LF)(SN); CONN-SMD_2P-P1.00_SM02B-SRSS-TB-LF-SN; LCSC Part C160402
M303: Compute-Module-4_H1.5mm; MPN SC0294; not fitted
Module301: ComputeModule5-CM5; Raspberry-Pi-5-Compute-Module_GPIO; Part Description 100 Position Connector Receptacle, Cent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
Module302: ComputeModule5-CM5; Raspberry-Pi-5-Compute-Module_HSS; Part Description 100 Position Connector Receptacle, Cent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

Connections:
+1V8: Module301.88 (+1.8v_(Output)), Module301.90 (+1.8v_(Output)); also elsewhere on the board
+3V3_PI: Module301.84 (+3.3v_(Output)), Module301.86 (+3.3v_(Output)); also elsewhere on the board
+5V: Module301.77 (+5v_(Input)), Module301.79 (+5v_(Input)), Module301.81 (+5v_(Input)), Module301.83 (+5v_(Input)), Module301.85 (+5v_(Input)), Module301.87 (+5v_(Input)); also elsewhere on the board
+BATT: CN1.1, Module301.76 (VBAT)
/CC1: Module301.94 (CC1); also elsewhere on the board
/CC2: Module301.96 (CC2); also elsewhere on the board
/CM5/BL_GPIO24: Module301.45 (GPIO24); also elsewhere on the board
/CM5/BT_nDis: Module301.91 (BT_nDisable)
/CM5/CAM_GPIO0: Module301.97 (CAM_GPIO0); also elsewhere on the board
/CM5/CAM_GPIO1: Module301.100 (CAM_GPIO1); also elsewhere on the board
/CM5/CS_GPIO18: Module301.49 (GPIO18); also elsewhere on the board
/CM5/DC_GPI25: Module301.41 (GPIO25); also elsewhere on the board
/CM5/DPHY0_P.C_N: Module302.127 (MIPI0_C_N); also elsewhere on the board
/CM5/DPHY0_P.C_P: Module302.129 (MIPI0_C_P); also elsewhere on the board
/CM5/DPHY0_P.D0_N: Module302.115 (MIPI0_D0_N); also elsewhere on the board
/CM5/DPHY0_P.D0_P: Module302.117 (MIPI0_D0_P); also elsewhere on the board
/CM5/DPHY0_P.D1_N: Module302.121 (MIPI0_D1_N); also elsewhere on the board
/CM5/DPHY0_P.D1_P: Module302.123 (MIPI0_D1_P); also elsewhere on the board
/CM5/DPHY0_P.D2_N: Module302.133 (MIPI0_D2_N); also elsewhere on the board
/CM5/DPHY0_P.D2_P: Module302.135 (MIPI0_D2_P); also elsewhere on the board
/CM5/DPHY0_P.D3_N: Module302.139 (MIPI0_D3_N); also elsewhere on the board
/CM5/DPHY0_P.D3_P: Module302.141 (MIPI0_D3_P); also elsewhere on the board
/CM5/DPHY1_P.C_N: Module302.187 (MIPI1_C_N)
/CM5/DPHY1_P.C_P: Module302.189 (MIPI1_C_P)
/CM5/DPHY1_P.D0_N: Module302.175 (MIPI1_D0_N)
/CM5/DPHY1_P.D0_P: Module302.177 (MIPI1_D0_P)
/CM5/DPHY1_P.D1_N: Module302.181 (MIPI1_D1_N)
/CM5/DPHY1_P.D1_P: Module302.183 (MIPI1_D1_P)
/CM5/DPHY1_P.D2_N: Module302.193 (MIPI1_D2_N)
/CM5/DPHY1_P.D2_P: Module302.195 (MIPI1_D2_P)
/CM5/DPHY1_P.D3_N: Module302.194 (MIPI1_D3_N)
/CM5/DPHY1_P.D3_P: Module302.196 (MIPI1_D3_P)
/CM5/EEPROM_nWP: Module301.20 (EEPROM_nWP); also elsewhere on the board
/CM5/ETH_PI.TRD0_N: Module301.10 (Ethernet_Pair0_N); also elsewhere on the board
/CM5/ETH_PI.TRD0_P: Module301.12 (Ethernet_Pair0_P); also elsewhere on the board
/CM5/ETH_PI.TRD1_N: Module301.6 (Ethernet_Pair1_N); also elsewhere on the board
/CM5/ETH_PI.TRD1_P: Module301.4 (Ethernet_Pair1_P); also elsewhere on the board
/CM5/ETH_PI.TRD2_N: Module301.9 (Ethernet_Pair2_N); also elsewhere on the board
/CM5/ETH_PI.TRD2_P: Module301.11 (Ethernet_Pair2_P); also elsewhere on the board
/CM5/ETH_PI.TRD3_N: Module301.5 (Ethernet_Pair3_N); also elsewhere on the board
/CM5/ETH_PI.TRD3_P: Module301.3 (Ethernet_Pair3_P); also elsewhere on the board
/CM5/ETH_nLED_ACTIVITY: Module301.15 (Ethernet_nLED3(3.3v)); also elsewhere on the board
/CM5/GLOBAL_EN: Module301.99 (PMIC_ENABLE)
/CM5/GPIO4: Module301.54 (GPIO4)
/CM5/GPIO5: Module301.34 (GPIO5)
/CM5/GPIO6: Module301.30 (GPIO6)
/CM5/GPIO7: Module301.37 (GPIO7)
/CM5/GPIO8: Module301.39 (GPIO8)
/CM5/GPIO9: Module301.40 (GPIO9)
/CM5/GPIO10: Module301.44 (GPIO10)
/CM5/GPIO11: Module301.38 (GPIO11)
/CM5/GPIO12: Module301.31 (GPIO12)
/CM5/GPIO13: Module301.28 (GPIO13)
/CM5/GPIO14: Module301.55 (GPIO14)
/CM5/GPIO15: Module301.51 (GPIO15)
/CM5/GPIO16: Module301.29 (GPIO16)
/CM5/GPIO17: Module301.50 (GPIO17)
/CM5/GPIO22: Module301.46 (GPIO22)
/CM5/GPIO23: Module301.47 (GPIO23)
/CM5/GPIO26: Module301.24 (GPIO26)
/CM5/GPIO_VREF: Module301.78 (GPIO_VREF(1.8v/3.3v_Input)); also elsewhere on the board
/CM5/HDMI1_CEC: Module302.149 (HDMI1_CEC)
/CM5/HDMI1_CK_N: Module302.166 (HDMI1_CLK_N)
/CM5/HDMI1_CK_P: Module302.164 (HDMI1_CLK_P)
/CM5/HDMI1_D0_N: Module302.160 (HDMI1_TX0_N)
/CM5/HDMI1_D0_P: Module302.158 (HDMI1_TX0_P)
/CM5/HDMI1_D1_N: Module302.154 (HDMI1_TX1_N)
/CM5/HDMI1_D1_P: Module302.152 (HDMI1_TX1_P)
/CM5/HDMI1_D2_N: Module302.148 (HDMI1_TX2_N)
/CM5/HDMI1_D2_P: Module302.146 (HDMI1_TX2_P)
/CM5/HDMI1_HOTPLUG: Module302.143 (HDMI1_HOTPLUG)
/CM5/HDMI1_SCL: Module302.147 (HDMI1_SCL)
/CM5/HDMI1_SDA: Module302.145 (HDMI1_SDA)
/CM5/HDMI_PI.CEC: Module302.151 (HDMI0_CEC); also elsewhere on the board
/CM5/HDMI_PI.CK_N: Module302.190 (HDMI0_CLK_N); also elsewhere on the board
/CM5/HDMI_PI.CK_P: Module302.188 (HDMI0_CLK_P); also elsewhere on the board
/CM5/HDMI_PI.D0_N: Module302.184 (HDMI0_TX0_N); also elsewhere on the board
/CM5/HDMI_PI.D0_P: Module302.182 (HDMI0_TX0_P); also elsewhere on the board
/CM5/HDMI_PI.D1_N: Module302.178 (HDMI0_TX1_N); also elsewhere on the board
/CM5/HDMI_PI.D1_P: Module302.176 (HDMI0_TX1_P); also elsewhere on the board
/CM5/HDMI_PI.D2_N: Module302.172 (HDMI0_TX2_N); also elsewhere on the board
/CM5/HDMI_PI.D2_P: Module302.170 (HDMI0_TX2_P); also elsewhere on the board
/CM5/HDMI_PI.HOTPLUG: Module302.153 (HDMI0_HOTPLUG); also elsewhere on the board
/CM5/HDMI_PI.SCL: Module302.200 (HDMI0_SCL); also elsewhere on the board
/CM5/HDMI_PI.SDA: Module302.199 (HDMI0_SDA); also elsewhere on the board
/CM5/ID_SC: Module301.35 (ID_SC)
/CM5/ID_SD: Module301.36 (ID_SD)
/CM5/MISO_GPIO19: Module301.26 (GPIO19); also elsewhere on the board
/CM5/MOSI_GPIO20: Module301.27 (GPIO20); also elsewhere on the board
/CM5/PCIE_PI.CLK_N: Module302.112 (PCIe_CLK_N); also elsewhere on the board
/CM5/PCIE_PI.CLK_P: Module302.110 (PCIe_CLK_P); also elsewhere on the board
/CM5/PCIE_PI.PWR_EN: Module302.106 (PCIE_PWR_EN); also elsewhere on the board
/CM5/PCIE_PI.RX_N: Module302.118 (PCIe_RX_N); also elsewhere on the board
/CM5/PCIE_PI.RX_P: Module302.116 (PCIe_RX_P); also elsewhere on the board
/CM5/PCIE_PI.TX_N: Module302.124 (PCIe_TX_N); also elsewhere on the board
/CM5/PCIE_PI.TX_P: Module302.122 (PCIe_TX_P); also elsewhere on the board
/CM5/PCIE_PI.nCLKREQ: Module302.102 (PCIe_nCLKREQ); also elsewhere on the board
/CM5/PCIE_PI.nRST: Module302.109 (PCIe_nRST); also elsewhere on the board
/CM5/PCIE_PI.nWAKE: Module302.104 (PCIE_nWAKE); also elsewhere on the board
/CM5/PI_nLED_PWR: Module301.95 (LED_nPWR); also elsewhere on the board
/CM5/PWM: Module301.19 (FAN_PWM); also elsewhere on the board
/CM5/PWR_BUT: Module301.92 (PWR_BUT); also elsewhere on the board
/CM5/RST_GPIO27: Module301.48 (GPIO27); also elsewhere on the board
/CM5/SCL0: Module301.80 (SCL0); also elsewhere on the board
/CM5/SCLK_GPIO21: Module301.25 (GPIO21); also elsewhere on the board
/CM5/SDA0: Module301.82 (SDA0); also elsewhere on the board
/CM5/SD_CLK: Module301.57 (SD_CLK)
/CM5/SD_CMD: Module301.62 (SD_CMD)
/CM5/SD_DAT0: Module301.63 (SD_DAT0)
/CM5/SD_DAT1: Module301.67 (SD_DAT1)
/CM5/SD_DAT2: Module301.69 (SD_DAT2)
/CM5/SD_DAT3: Module301.61 (SD_DAT3)
/CM5/SD_PWR_ON: Module301.75 (SD_PWR_ON)
/CM5/SYNC_OUT: Module301.18 (Ethernet_SYNC_OUT(3.3v))
/CM5/TACHO: Module301.16 (FAN_TACHO); also elsewhere on the board
/CM5/USB2P.D_N: Module302.136 (USB3-0-D_N); also elsewhere on the board
/CM5/USB2P.D_P: Module302.134 (USB3-0-D_P); also elsewhere on the board
/CM5/USB3-0-RX_N: Module302.128 (USB3-0-RX_N)
/CM5/USB3-0-RX_P: Module302.130 (USB3-0-RX_P)
/CM5/USB3-0-TX_N: Module302.140 (USB3-0-TX_N)
/CM5/USB3-0-TX_P: Module302.142 (USB3-0-TX_P)
/CM5/USB3-1-D_N: Module302.165 (USB3-1-D_N)
/CM5/USB3-1-D_P: Module302.163 (USB3-1-D_P)
/CM5/USB3-1-RX_N: Module302.157 (USB3-1-RX_N)
/CM5/USB3-1-RX_P: Module302.159 (USB3-1-RX_P)
/CM5/USB3-1-TX_N: Module302.169 (USB3-1-TX_N)
/CM5/USB3-1-TX_P: Module302.171 (USB3-1-TX_P)
/CM5/USBOTG_ID: Module302.101 (USB_OTG_ID)
/CM5/VBUS_EN: Module302.111 (VBUS_EN); also elsewhere on the board
/CM5/WL_nDis: Module301.89 (WiFi_nDisable)
/CM5/nLED_ACTIVITY: Module301.21 (LED_nACT); also elsewhere on the board
/CM5/nLED_SPEED_100_1000: Module301.17 (Ethernet_nLED2(3.3v)); also elsewhere on the board
/CM5/nRPIBOOT: Module301.93 (nRPIBOOT); also elsewhere on the board
/IO/SCL: Module301.56 (GPIO3); also elsewhere on the board
/IO/SDA: Module301.58 (GPIO2); also elsewhere on the board
/USB_C.D_N: Module302.103 (USB2_N); also elsewhere on the board
/USB_C.D_P: Module302.105 (USB2_P); also elsewhere on the board
GND: CN1.2, Module301.1 (GND), Module301.2 (GND), Module301.7 (GND), Module301.8 (GND), Module301.13 (GND), Module301.14 (GND), Module301.22 (GND), Module301.23 (GND), Module301.32 (GND), Module301.33 (GND), Module301.42 (GND), Module301.43 (GND), Module301.52 (GND), Module301.53 (GND), Module301.59 (GND), Module301.60 (GND), Module301.65 (GND), Module301.66 (GND), Module301.71 (GND), Module301.74 (GND), Module301.98 (GND), Module302.107 (GND), Module302.108 (GND), Module302.113 (GND), Module302.114 (GND), Module302.119 (GND), Module302.120 (GND), Module302.125 (GND), Module302.126 (GND), Module302.131 (GND), Module302.132 (GND), Module302.137 (GND), Module302.138 (GND), Module302.144 (GND), Module302.150 (GND), Module302.155 (GND), Module302.156 (GND), Module302.161 (GND), Module302.162 (GND), Module302.167 (GND), Module302.168 (GND), Module302.173 (GND), Module302.174 (GND), Module302.179 (GND), Module302.180 (GND), Module302.185 (GND), Module302.186 (GND), Module302.191 (GND), Module302.192 (GND), Module302.197 (GND), Module302.198 (GND); also elsewhere on the board

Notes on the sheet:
CM mechanicals
[CM5]

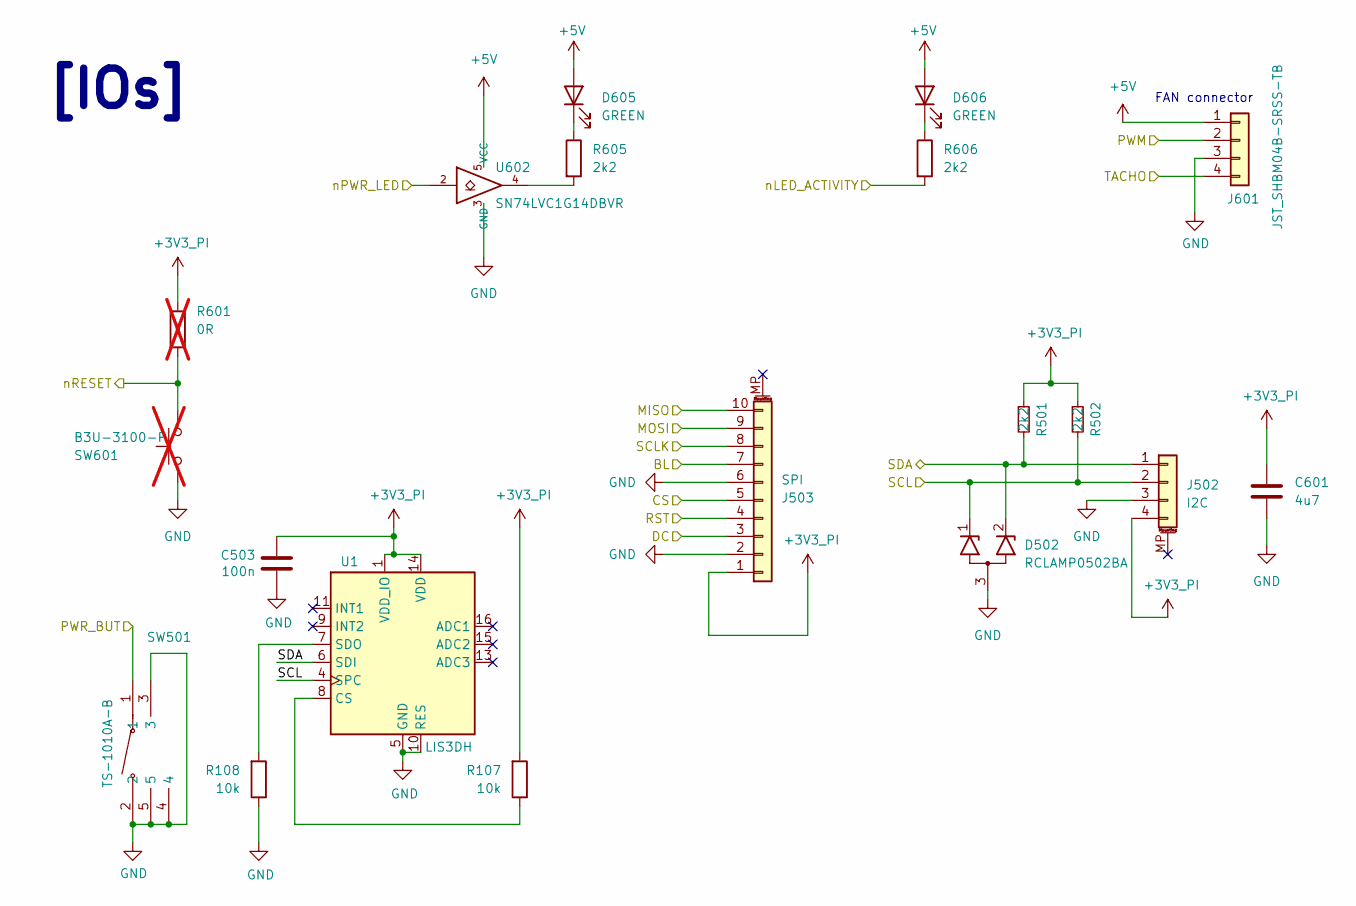
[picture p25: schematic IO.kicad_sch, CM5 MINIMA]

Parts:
C503: 100n; C_0402_1005Metric; Part Description 0.1uF 10% 16V Ceramic Capacitor X7R 040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
C601: 4u7; C_0805_2012Metric; Part Description 4.7uF 10% 10V Ceramic Capacitor X7R 080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
D502: RCLAMP0502BA; SOT-416
D605, D606: GREEN; LED-SMD_L1.7-W0.6-RD
J502: I2C; JST_SH_BM04B-SRSS-TB_1x04-1MP_P1.00mm_Vertical
J503: SPI; JST_SUR_BM10B-SURS-TF_1x10-1MP_P0.80mm_Vertical
J601: JST_SHBM04B-SRSS-TB; JST_SH_BM04B-SRSS-TB_1x04-1MP_P1.00mm_Vertical; Part Description 4 pin vertical 1mm pitch connector
R107, R108: 10k; R_0402_1005Metric
R501, R502, R605, R606: 2k2; R_0402_1005Metric
R601: 0R; R_0402_1005Metric; not fitted
SW501: TS-1010A-B; SW-SMD_TS-1010A-B; LCSC Part C381059
SW601: B3U-3100-P; SW_SPST_B3U-3100P-B; not fitted
U1: LIS3DH; LGA-16_3x3mm_P0.5mm_LayoutBorder3x5y
U602: SN74LVC1G14DBVR; SOT-353_SC-70-5; Part Description Buffer, Non-Inverting 1 Element 1 Bit p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

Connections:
+3V3_PI: C503.1, C601.1, J502.4, J503.1, R107.2, R501.1, R502.1, R601.1, U1.1 (VDD_IO), U1.14 (VDD); also elsewhere on the board
+5V: D605.2 (A), D606.2 (A), J601.1, U602.5 (VCC); also elsewhere on the board
/CM5/BL_GPIO24: J503.7; also elsewhere on the board
/CM5/CS_GPIO18: J503.5; also elsewhere on the board
/CM5/DC_GPI25: J503.3; also elsewhere on the board
/CM5/MISO_GPIO19: J503.10; also elsewhere on the board
/CM5/MOSI_GPIO20: J503.9; also elsewhere on the board
/CM5/PI_nLED_PWR: U602.2; also elsewhere on the board
/CM5/PWM: J601.2; also elsewhere on the board
/CM5/PWR_BUT: SW501.1; also elsewhere on the board
/CM5/RST_GPIO27: J503.4; also elsewhere on the board
/CM5/SCLK_GPIO21: J503.8; also elsewhere on the board
/CM5/TACHO: J601.4; also elsewhere on the board
/CM5/nLED_ACTIVITY: R606.2; also elsewhere on the board
/IO/SCL: D502.1 (K1), J502.2, R502.2, U1.4 (SPC); also elsewhere on the board
/IO/SDA: D502.2 (K2), J502.1, R501.2, U1.6 (SDI); also elsewhere on the board
GND: C503.2, C601.2, D502.3 (A), J502.3, J503.2, J503.6, J601.3, R108.1, SW501.2, SW501.3, SW501.4, SW501.5, SW601.2, U1.5 (GND), U1.10 (RES), U1.12 (GND), U602.3 (GND); also elsewhere on the board
unnamed: D605.1 (K), R605.1
unnamed: D606.1 (K), R606.1
unnamed: R601.2, SW601.1
unnamed: R605.2, U602.4
unnamed: R107.1, U1.8 (CS)
unnamed: R108.2, U1.7 (SDO)

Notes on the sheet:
[IOs]
FAN connector

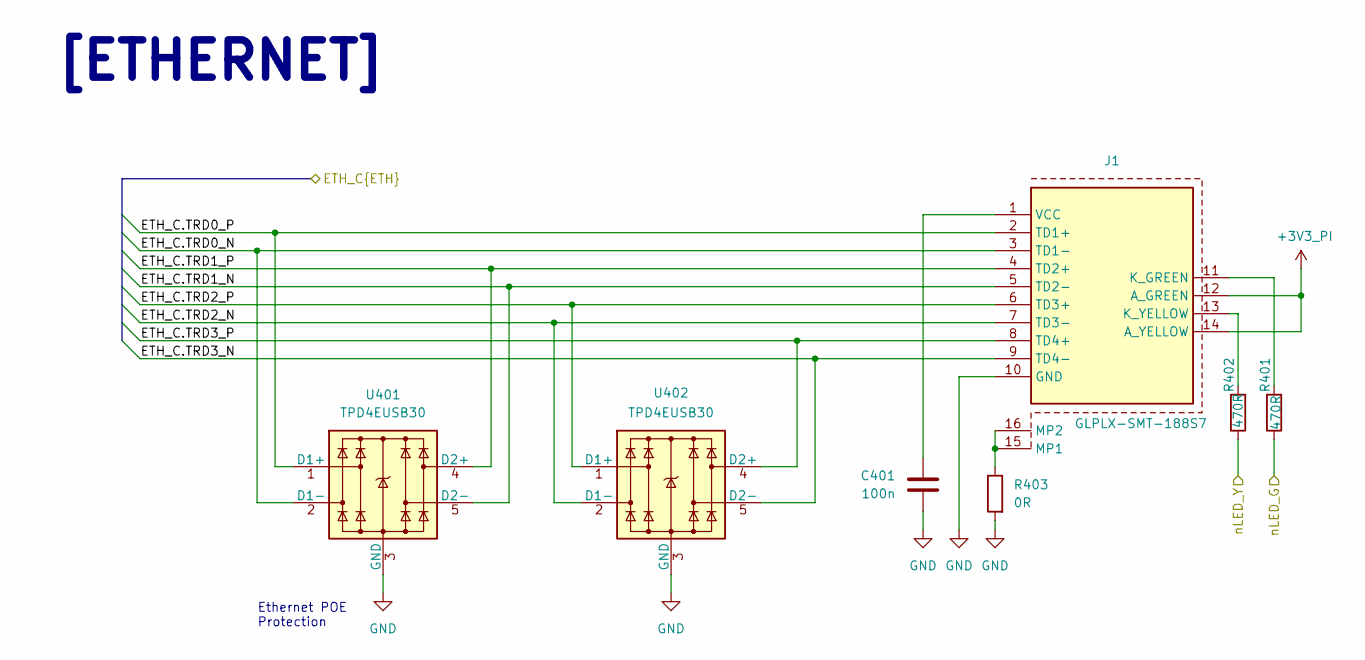
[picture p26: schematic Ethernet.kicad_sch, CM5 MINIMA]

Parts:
C401: 100n; C_0402_1005Metric; Part Description 0.1uF 10% 16V Ceramic Capacitor X7R 040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
J1: GLPLX-SMT-188S7; GLPLXSMT188S7QQYG; Manufacturer_Part_Number GLPLX-SMT-188S7-QQ-Y/G; Mouser Part Number 806-GLPLXSMT188S7-YG
R401, R402: 470R; R_0402_1005Metric
R403: 0R; R_0402_1005Metric
U401, U402: TPD4EUSB30; USON-10_2.5x1.0mm_P0.5mm; Part Description Quad TVS diode for high speed signals (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

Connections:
+3V3_PI: J1.12 (A_GREEN), J1.14 (A_YELLOW); also elsewhere on the board
/CM5/ETH_PI.TRD0_N: J1.3 (TD1-), U401.2 (D1-), U401.9; also elsewhere on the board
/CM5/ETH_PI.TRD0_P: J1.2 (TD1+), U401.1 (D1+), U401.10; also elsewhere on the board
/CM5/ETH_PI.TRD1_N: J1.5 (TD2-), U401.5 (D2-), U401.6; also elsewhere on the board
/CM5/ETH_PI.TRD1_P: J1.4 (TD2+), U401.4 (D2+), U401.7; also elsewhere on the board
/CM5/ETH_PI.TRD2_N: J1.7 (TD3-), U402.2 (D1-), U402.9; also elsewhere on the board
/CM5/ETH_PI.TRD2_P: J1.6 (TD3+), U402.1 (D1+), U402.10; also elsewhere on the board
/CM5/ETH_PI.TRD3_N: J1.9 (TD4-), U402.5 (D2-), U402.6; also elsewhere on the board
/CM5/ETH_PI.TRD3_P: J1.8 (TD4+), U402.4 (D2+), U402.7; also elsewhere on the board
/CM5/ETH_nLED_ACTIVITY: R401.1; also elsewhere on the board
/CM5/nLED_SPEED_100_1000: R402.1; also elsewhere on the board
GND: C401.2, J1.10 (GND), R403.2, U401.3 (GND), U401.8 (GND), U402.3 (GND), U402.8 (GND); also elsewhere on the board
unnamed: J1.11 (K_GREEN), R401.2
unnamed: J1.13 (K_YELLOW), R402.2
unnamed: J1.15 (MP1), J1.16 (MP2), R403.1
unnamed: C401.1, J1.1 (VCC)

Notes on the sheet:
[ETHERNET]
Ethernet POE Protection

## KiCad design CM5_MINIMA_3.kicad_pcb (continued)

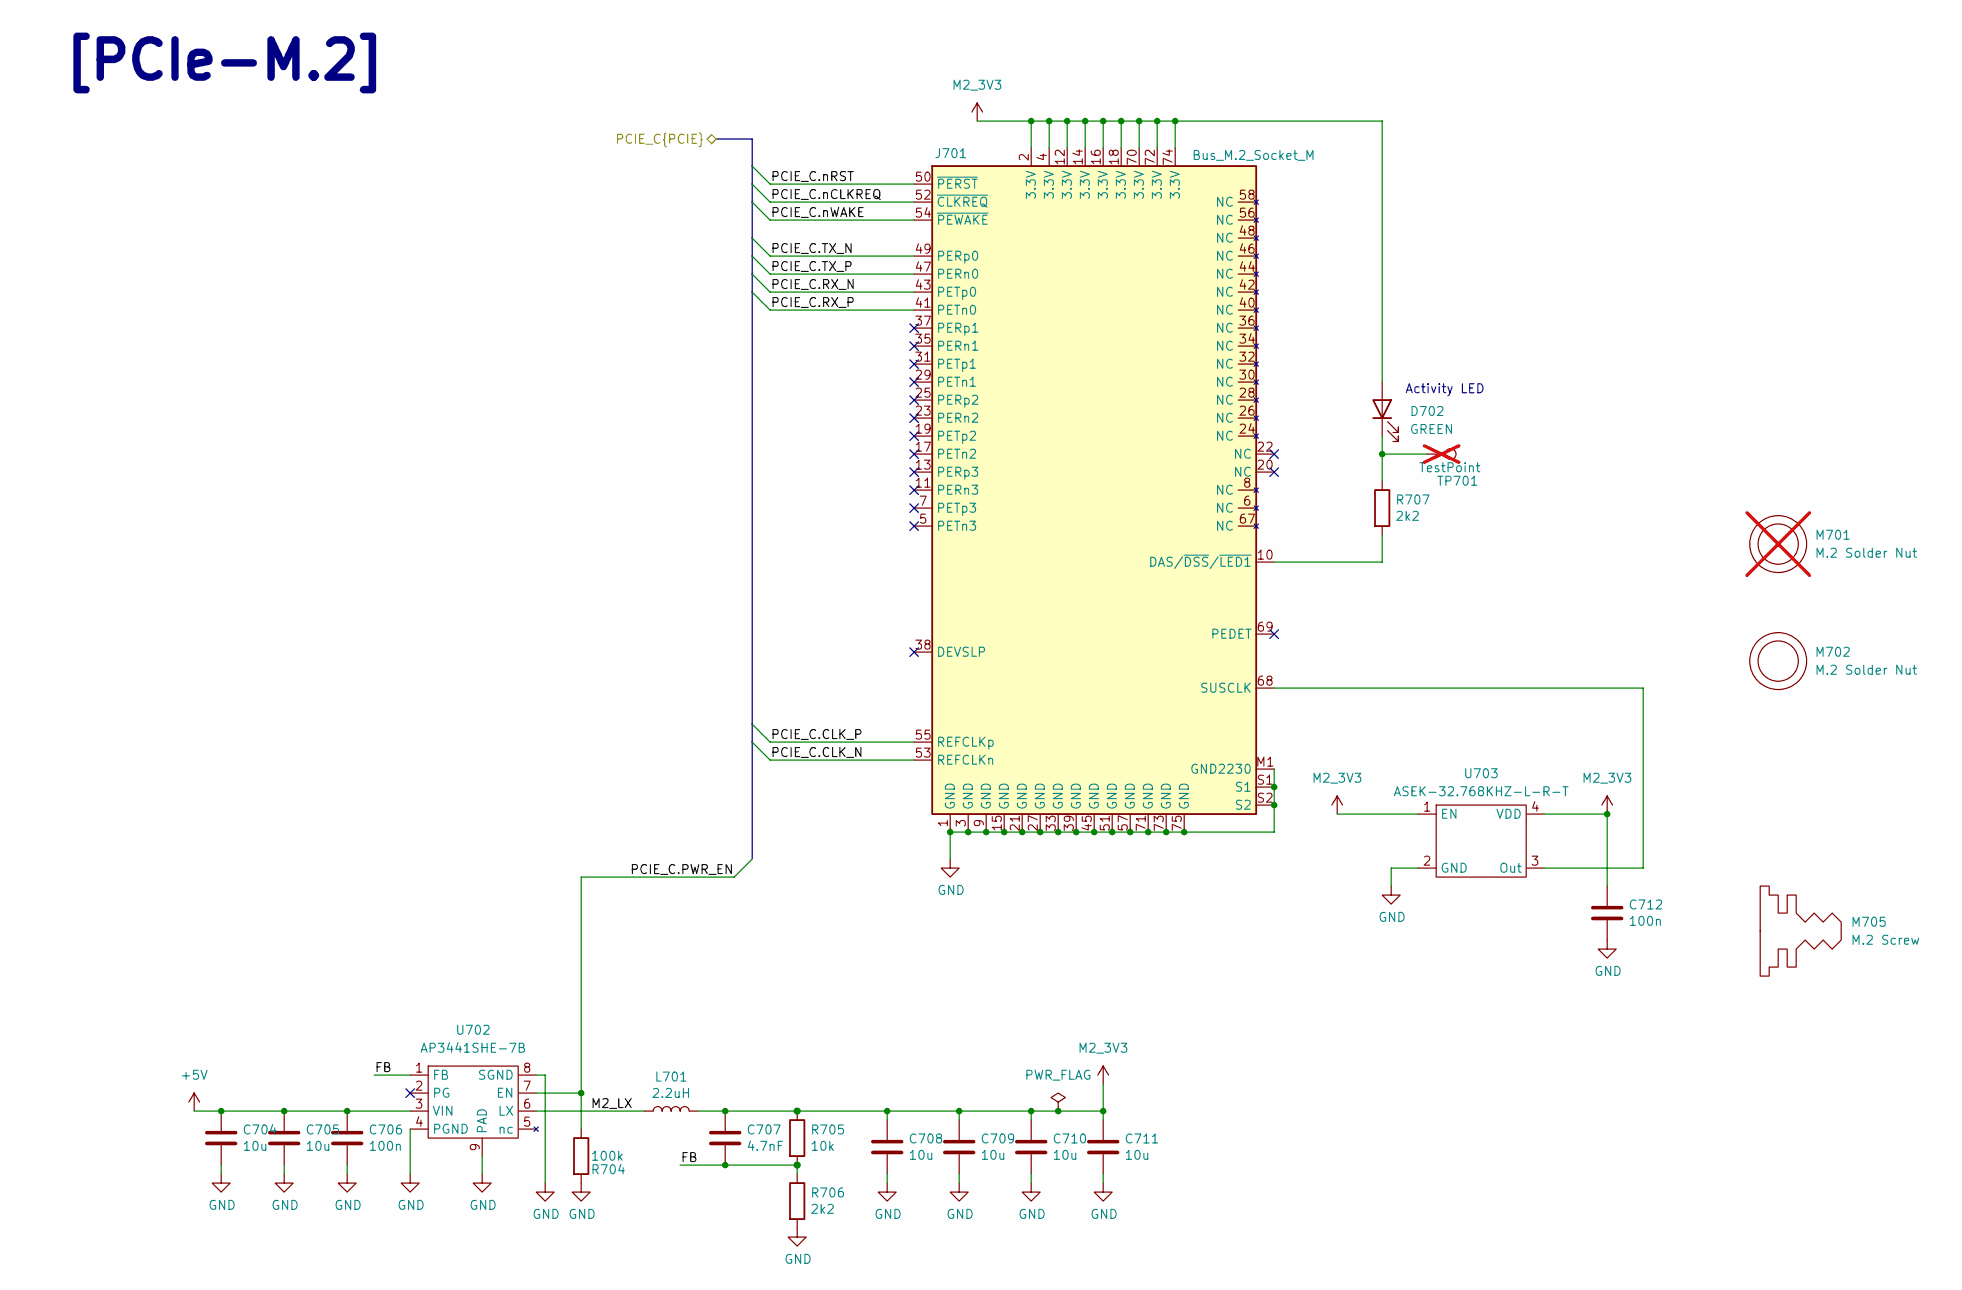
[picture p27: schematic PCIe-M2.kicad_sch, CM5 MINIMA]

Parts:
C704, C705, C708, C709, C710, C711: 10u; C_0805_2012Metric; Part Description 10uF 10% 10V Ceramic Capacitor X7R 0805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
C706, C712: 100n; C_0402_1005Metric; Part Description 0.1uF 10% 16V Ceramic Capacitor X7R 040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
C707: 4.7nF; C_0402_1005Metric; Part Description 4.7nF capacitor 0402
D702: GREEN; LED-SMD_L1.7-W0.6-RD
J701: Bus_M.2_Socket_M; M.2 M Key socket_2230_2242; Part Description M.2 M Key connector
L701: 2.2uH; L_Coilcraft_XAL5030-XXX; Part Description Inductor, SMT, 2u2, IRMS=7A, ISAT=8.1A,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
M701: M.2 Solder Nut; MountingHole_3mm_Pad; Part Description Solder nut for M.2 slot; not fitted
M702: M.2 Solder Nut; MountingHole_3mm_Pad; Part Description Solder nut for M.2 slot
M705: M.2 Screw; Part Description M.2 Screw
R704: 100k; R_0402_1005Metric
R705: 10k; R_0402_1005Metric
R706: 2k2; R_0402_1005Metric
R707: 2k2; R_0402_1005Metric; Part Description Resistor 1K M1005 1% 63mW
TP701: TestPoint; TestPoint_Pad_2.0x2.0mm; Part Description Test point; not fitted
U702: AP3441SHE-7B; DFN-8-1EP_2x2mm_P0.5mm_EP1.05x1.75mm; Part Description 3A DC-DC converter
U703: ASEK-32.768KHZ-L-R-T; Crystal_SMD_3225-4Pin_3.2x2.5mm; Part Description 32KHz Xtal oscilator

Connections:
+5V: C704.1, C705.1, C706.1, U702.3 (VIN); also elsewhere on the board
/CM5/PCIE_PI.CLK_N: J701.53 (REFCLKn); also elsewhere on the board
/CM5/PCIE_PI.CLK_P: J701.55 (REFCLKp); also elsewhere on the board
/CM5/PCIE_PI.PWR_EN: R704.1, U702.7 (EN); also elsewhere on the board
/CM5/PCIE_PI.RX_N: J701.43 (PETp0); also elsewhere on the board
/CM5/PCIE_PI.RX_P: J701.41 (PETn0); also elsewhere on the board
/CM5/PCIE_PI.TX_N: J701.49 (PERp0); also elsewhere on the board
/CM5/PCIE_PI.TX_P: J701.47 (PERn0); also elsewhere on the board
/CM5/PCIE_PI.nCLKREQ: J701.52 (~CLKREQ); also elsewhere on the board
/CM5/PCIE_PI.nRST: J701.50 (~PERST); also elsewhere on the board
/CM5/PCIE_PI.nWAKE: J701.54 (~PEWAKE); also elsewhere on the board
/PCIe-M2/FB: C707.2, R705.2, R706.1, U702.1 (FB)
/PCIe-M2/M2_LX: L701.1, U702.6 (LX)
GND: C704.2, C705.2, C706.2, C708.2, C709.2, C710.2, C711.2, C712.2, J701.1 (GND), J701.3 (GND), J701.9 (GND), J701.15 (GND), J701.21 (GND), J701.27 (GND), J701.33 (GND), J701.39 (GND), J701.45 (GND), J701.51 (GND), J701.57 (GND), J701.71 (GND), J701.73 (GND), J701.75 (GND), J701.M1 (GND2230), J701.S1, J701.S2, R704.2, R706.2, U702.4 (PGND), U702.8 (SGND), U702.9 (PAD), U703.2 (GND); also elsewhere on the board
M2_3V3: C707.1, C708.1, C709.1, C710.1, C711.1, C712.1, D702.2 (A), J701.2 (3.3V), J701.4 (3.3V), J701.12 (3.3V), J701.14 (3.3V), J701.16 (3.3V), J701.18 (3.3V), J701.70 (3.3V), J701.72 (3.3V), J701.74 (3.3V), L701.2, R705.1, U703.1 (EN), U703.4 (VDD)
unnamed: D702.1 (K), R707.1, TP701.1
unnamed: J701.10 (DAS/~DSS/~LED1), R707.2
unnamed: J701.68 (SUSCLK), U703.3 (Out)

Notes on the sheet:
[PCIe-M.2]
Activity LED

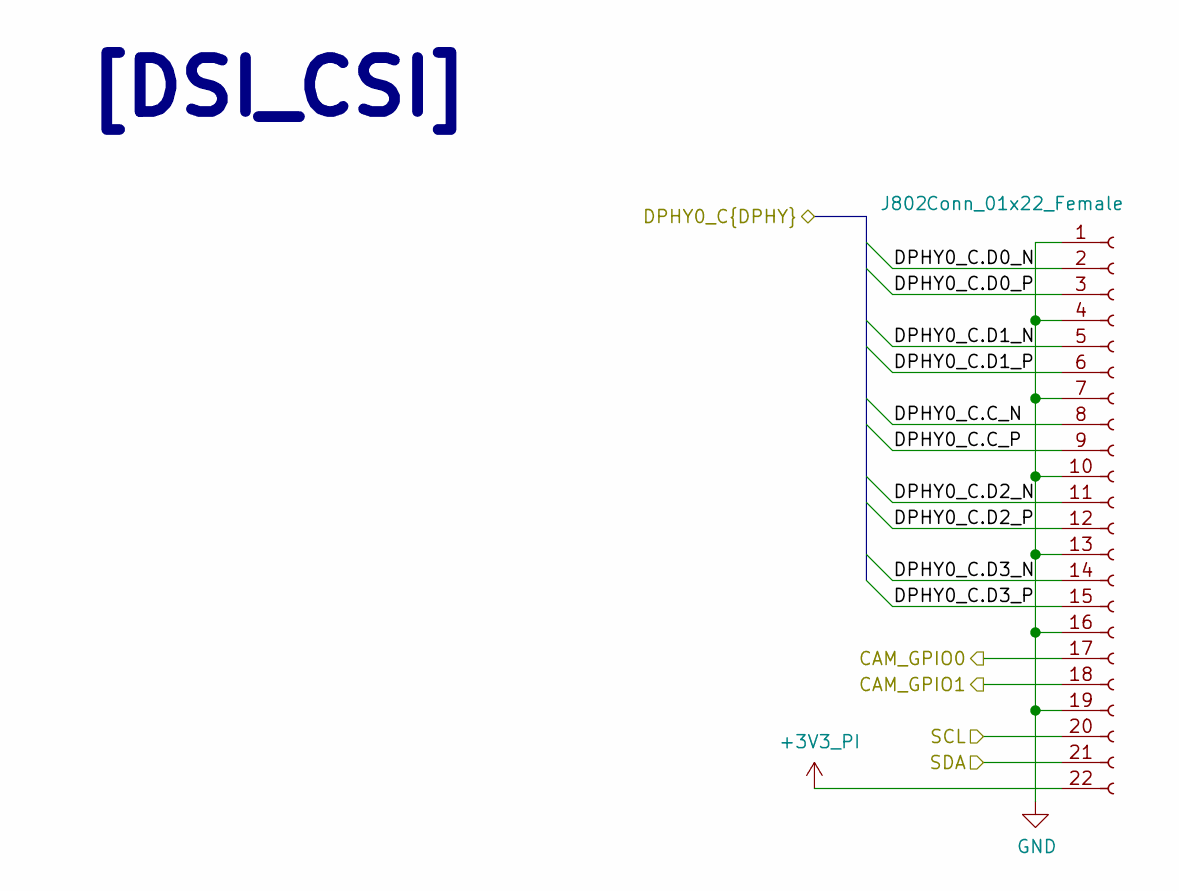
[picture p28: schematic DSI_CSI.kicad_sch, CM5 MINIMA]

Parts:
J802: Conn_01x22_Female; Hirose_FH12-22S-0.5SH_1x22-1MP_P0.50mm_Horizontal; Part Description 22 Position FFC, FPC Connector Contacts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

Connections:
+3V3_PI: J802.22; also elsewhere on the board
/CM5/CAM_GPIO0: J802.17; also elsewhere on the board
/CM5/CAM_GPIO1: J802.18; also elsewhere on the board
/CM5/DPHY0_P.C_N: J802.8; also elsewhere on the board
/CM5/DPHY0_P.C_P: J802.9; also elsewhere on the board
/CM5/DPHY0_P.D0_N: J802.2; also elsewhere on the board
/CM5/DPHY0_P.D0_P: J802.3; also elsewhere on the board
/CM5/DPHY0_P.D1_N: J802.5; also elsewhere on the board
/CM5/DPHY0_P.D1_P: J802.6; also elsewhere on the board
/CM5/DPHY0_P.D2_N: J802.11; also elsewhere on the board
/CM5/DPHY0_P.D2_P: J802.12; also elsewhere on the board
/CM5/DPHY0_P.D3_N: J802.14; also elsewhere on the board
/CM5/DPHY0_P.D3_P: J802.15; also elsewhere on the board
/CM5/SCL0: J802.20; also elsewhere on the board
/CM5/SDA0: J802.21; also elsewhere on the board
GND: J802.1, J802.4, J802.7, J802.10, J802.13, J802.16, J802.19; also elsewhere on the board

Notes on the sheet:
[DSI_CSI]

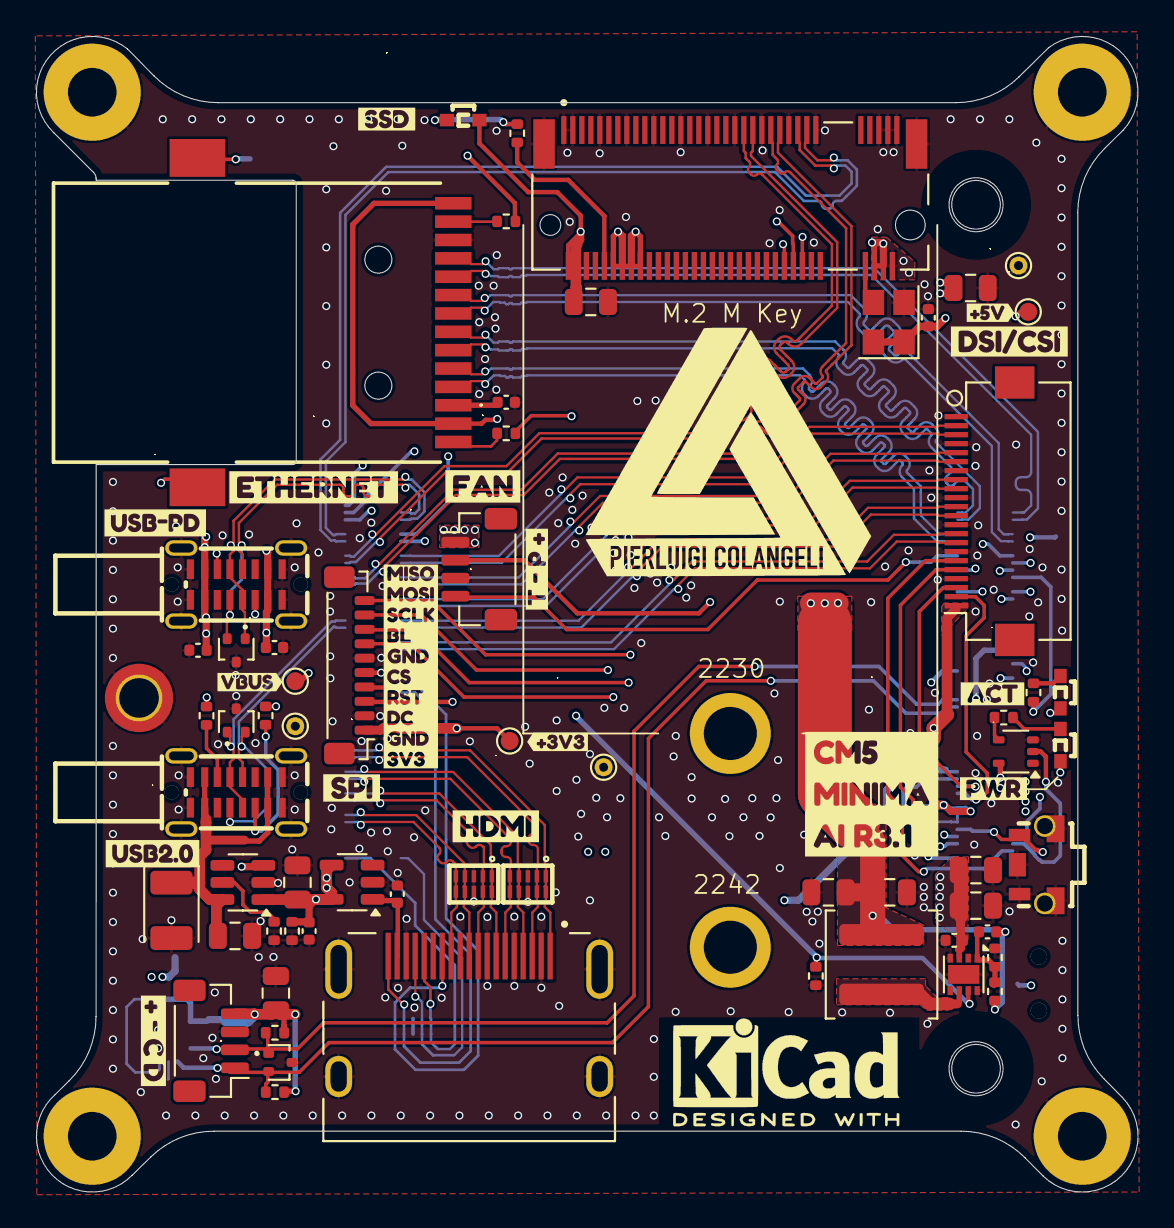
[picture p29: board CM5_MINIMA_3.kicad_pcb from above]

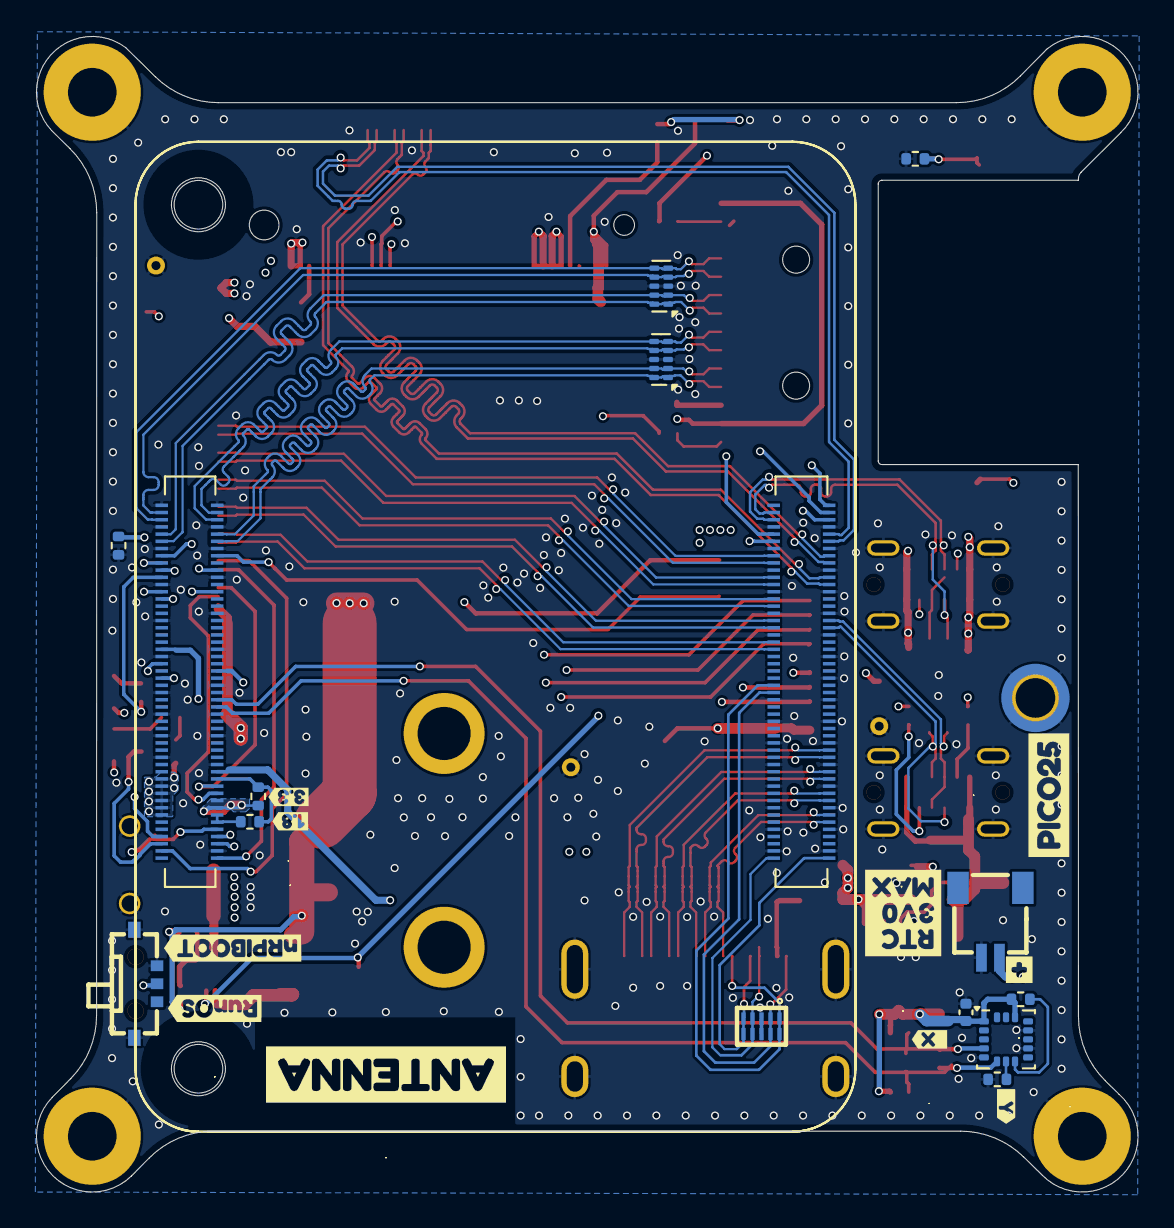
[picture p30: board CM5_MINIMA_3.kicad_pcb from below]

Board: 6 copper layers, 61.2 x 64.2 mm, 111 parts (25 on the bottom side), 95 nets.

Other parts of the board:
kibuzzard-67CC6BA6: G***; kibuzzard-67CC6BA6
kibuzzard-67CC6BD3: G***; kibuzzard-67CC6BD3
kibuzzard-67CC6D9E: G***; kibuzzard-67CC6D9E
kibuzzard-67CC6D94: G***; kibuzzard-67CC6D94
kibuzzard-67CC7445: G***; kibuzzard-67CC7445
kibuzzard-67EBAC4C: G***; kibuzzard-67EBAC4C
kibuzzard-67EBB9C1: G***; kibuzzard-67EBB9C1
kibuzzard-67EBD21C: G***; kibuzzard-67EBD21C
kibuzzard-67EBD221: G***; kibuzzard-67EBD221
kibuzzard-67EBEF55: G***; kibuzzard-67EBEF55
kibuzzard-67EBF0A0: G***; kibuzzard-67EBF0A0
kibuzzard-67EBF14E: G***; kibuzzard-67EBF14E
kibuzzard-67EBF015: G***; kibuzzard-67EBF015
kibuzzard-675DA838: G***; kibuzzard-675DA838
kibuzzard-675DA850: G***; kibuzzard-675DA850
kibuzzard-675DA866: G***; kibuzzard-675DA866
kibuzzard-675EDCA4: G***; kibuzzard-675EDCA4
kibuzzard-675EDCB9: G***; kibuzzard-675EDCB9
kibuzzard-6772D327: G***; kibuzzard-6772D327
kibuzzard-6772DA33: G***; kibuzzard-6772DA33
kibuzzard-6773B9CA: G***; kibuzzard-6773B9CA
kibuzzard-6773B9F7: G***; kibuzzard-6773B9F7
kibuzzard-6773BA89: G***; kibuzzard-6773BA89
kibuzzard-6773C2D7: G***; kibuzzard-6773C2D7
kibuzzard-6773C222: G***; kibuzzard-6773C222
kibuzzard-6773C376: G***; kibuzzard-6773C376
kibuzzard-67795592: G***; kibuzzard-67795592

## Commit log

2025-04-01 DRC and prod files
    [CM5.kicad_sch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]
2025-04-01 save exit
    [CM5_MINIMA_3.kicad_pcb]
2025-04-03 swapped I2C bus from 0 to 1
    [CM5.kicad_sch, CM5_MINIMA_3.kicad_pcb, CM5_MINIMA_3.kicad_sch]
2025-04-03 drc ok
    [CM5_MINIMA_3.kicad_pcb]
2025-04-08 eth PCB new
    [CM5_MINIMA_3-CuBottom.gbr, CM5_MINIMA_3-CuIn1.gbr, CM5_MINIMA_3-CuIn2.gbr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]
2025-06-25 assembly plot
    [CM5_MINIMA_3.kicad_pcb]
2025-08-29 NEXTPCB production files
    [CM5_MINIMA_3-CuBottom.gbr, CM5_MINIMA_3-CuIn1.gbr, CM5_MINIMA_3-CuIn2.gbr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]
2025-09-30 case added
    [MINIMA CASE 3_BOX v1.step]
2026-01-22 STEP upload
    [CM5_MINIMA_3.kicad_pcb]

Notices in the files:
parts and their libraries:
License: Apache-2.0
